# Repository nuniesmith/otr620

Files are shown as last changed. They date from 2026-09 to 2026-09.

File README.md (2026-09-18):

# Truck GPS Mount & Telemetry System (`truck-gps`)

A modular, parametric mount for the upper dash cubby in a **2022 Volvo VNL 860**, designed for a **Garmin OTR620** GPS, with integrated accessory shelves, real-time telemetry, and smart controller-based cooling/lighting.

This repository, formerly specific to the OTR620, has been restructured into a generic **`truck-gps`** project to host both mechanical (STL/CAD) files and software (Raspberry Pi/telemetry) code.

**Current status:** the repository contains the V3.1 mechanical fit prototype and earlier CAD sessions. The four v0.2 test pieces are currently being printed; physical fit results remain pending. A runnable simulation-first controller now lives in `src/pi/`: fan hysteresis, full-speed override, LED commands, sensor-fault handling and text/JSON status. Physical GPIO/PWM, live sensors, OLED, telemetry and revised cooling/power hardware remain unimplemented and untested.

Repository: [nuniesmith/truck-gps](https://github.com/nuniesmith/truck-gps).

---

## Documentation Index

- [README.md](README.md): Project overview, directory structure, system architecture, and electrical planning.
- [src/pi/README.md](src/pi/README.md): Run the controller simulation, tests, configuration and example service.
- [docs/pi-setup.md](docs/pi-setup.md): Selected fan, Pi review findings, software implementation and bench setup plan.
- [docs/todo.md](docs/todo.md): Master planning, task tracking, measurements, and physical test records.
- [docs/chats.md](docs/chats.md): Historical session logs (v0.1, v0.2, and v0.3) preserving earlier design rationale and prompts.
- [src/stl/v0.3/README.md](src/stl/v0.3/README.md): Current V3.1 print sequence, hardware, assembly and OpenSCAD export instructions.
- [docs/notes.md](docs/notes.md): Raw project ideas and planning notes.
- [docs/tomtom-api.md](docs/tomtom-api.md): TomTom Orbis Map, Routing, and Traffic API free tier and integration details.
- [docs/google-maps-api.md](docs/google-maps-api.md): Google Maps Platform free tier, Essentials, and Pro API configurations.

---

## Repository Structure

```
truck-gps/
├── README.md               # Main project file
├── docs/                   # Documentation, specifications, and notes
│   ├── todo.md             # Master task list and physical checklists
│   ├── chats.md            # Conversation archive from design sessions
│   ├── tomtom-api.md       # TomTom Orbis & legacy Maps pricing/specs
│   └── google-maps-api.md  # Google Maps pricing and capability reference
└── src/                    # Source code and physical designs
    ├── pi/                 # Runnable controller simulation; hardware and telemetry pending
    └── stl/                # 3D printer files (OpenSCAD & STLs grouped by design versions)
        ├── v0.1/           # First-generation design files
        ├── v0.2/           # Second-generation design files
        └── v0.3/           # V3.1 parametric mount & coupon test models
```

### Design sessions

| Directory | Origin | Role |
|---|---|---|
| [src/stl/v0.1](src/stl/v0.1) | First Claude session | Original insert and fit tests |
| [src/stl/v0.2](src/stl/v0.2) | Second Claude session | Rubber pads and accessory shelf |
| [src/stl/v0.3](src/stl/v0.3) | This ChatGPT session | V3.1 faceplate hardware, revised shelf and 12 STL files |

The session directory `v0.3` contains the CAD revision named **V3.1**; these are different naming schemes. Earlier `src/v0.x` paths and repository names in [the chat archive](docs/chats.md) are historical. Use the current paths above when locating files.

### First print checks

Start with [the V3.1 printing instructions](src/stl/v0.3/README.md#print-now-without-the-gps) and record results in [the task checklist](docs/todo.md#1-truck-and-accessory-tests--next-work). Print the truck frame, depth gauges, M2 hardware coupons and accessory outlines before the full assembly. The GPS housing, rear ports, gasket overlap and power requirements remain provisional until verified on the actual unit.

---

## System Architecture: Telemetry & Home Map

The truck has a stable **Starlink Wi-Fi** network, allowing the in-cab system to connect to the internet in real time.

```mermaid
flowchart TD
    subgraph Truck [Truck System]
        GPS_HW[Garmin OTR620]
        Pi_Cab[Raspberry Pi / Controller] -- Reads GPS Data --> Telemetry_Svc[Telemetry Service]
        Power_Supply[Power Delivery Module] --> Pi_Cab
        Power_Supply --> GPS_HW
    end

    subgraph Cloud [Secure Overlay Network]
        Tailscale[Tailscale VPN Overlay]
    end

    subgraph Home [Home Display System]
        Pi_Home[Raspberry Pi HDMI Receiver] -- Requests Webpage --> Pi_Cab
        TV[Home TV/Monitor] -- Renders Live Map --> Pi_Home
    end

    Pi_Cab <--> Tailscale
    Pi_Home <--> Tailscale
    Telemetry_Svc -- Serves Map & Live Position --> Pi_Home
```

### Tracking Workflow:
1. **Telemetry & GPS Capture (planned):** Select a supported GNSS input. A live position interface from the OTR620 has not been verified; an external receiver may be needed.
2. **Tailscale Private Network:** Both the truck Raspberry Pi and the home Raspberry Pi are enrolled in a private **Tailscale** network. This eliminates public IP exposure and port-forwarding issues.
3. **Home Display:** A Raspberry Pi connected to a TV/monitor at home loads a local webpage hosted by the truck Raspberry Pi via its Tailscale IP address.
4. **Real-time Map:** The page displays a high-resolution map of Canada and the United States with a custom truck icon representing your live location.
5. **Historical Logs:** The system logs traveled distance (km/miles) and states/provinces/countries visited per calendar year.
6. **Live Traffic:** The map consumes real-time traffic alerts using **TomTom Orbis Traffic** or **Google Maps** APIs on their generous free tiers.

---

## Power Strategy: Single vs. Dual USB-C Input

The front of the mounting bracket will feature physical toggle switches/buttons allowing manual control over individual power lines:
- **Main Power** (Master cut-off)
- **GPS Power**
- **Blue LEDs Power**
- **Cooling Fan Power**

We have evaluated two power routing topologies for the back of the bracket:

### Option A: Single USB-C Cable (Future candidate)
* **Description:** A single USB-C PD (Power Delivery) source powers the entire bracket. An internal buck converter regulates the input down to stable 5V lines.
* **Pros:**
  * Clean single-cable aesthetic behind the bracket.
  * Easy routing down the Volvo VNL dash.
  * Simplified physical plug-in sequence.
* **Cons:**
  * Requires robust internal step-down circuitry (e.g., converting 9V/12V PD to 5V @ 4A).
  * High-power charging (AirPods + GPS + Fan + Pi) could introduce electrical noise or heat.
  * Single point of failure for the entire system.

### Option B: Separate GPS and auxiliary supplies (Initial bring-up)
* **Description:** One USB-C cable runs directly to the Garmin GPS, while a second USB-C cable powers the Raspberry Pi and auxiliary components separately.
* **Pros:**
  * Separate supply paths for the Garmin and experimental accessories; a shared upstream source or ground can still couple faults.
  * Avoids a combined converter during initial tests; each output still needs appropriate regulation, protection and cabling.
  * If the Pi hangs or crashes, the GPS remains fully powered and functional.
* **Cons:**
  * Looks cluttered with two separate cables exiting the back of the bracket.
  * Uses up two USB power outlets in the truck's dashboard area.

---

## Selected controller: Raspberry Pi Zero 2 W

Use **Raspberry Pi Zero 2 W with Raspberry Pi OS Lite** as the host. The user selected a full Linux OS for SSH, Tailscale, telemetry and the home-map service while retaining low-level accessory control. A Pico is no longer the primary-controller plan.

I²C supports the selected OLED, 1-Wire supports the temperature sensors, and GPIO supports buttons and accessory control interfaces. Select a verified hardware PWM backend for fan speed; the old `RPi.GPIO.PWM()` example does not provide it. Keep fan control independent of network and display availability.

Allow for the board's micro-USB connectors, GPIO header, microSD access and 2.4 GHz Wi-Fi when designing the mount. [Raspberry Pi Zero 2 W specifications](https://www.raspberrypi.com/products/raspberry-pi-zero-2-w/)

Run [the controller simulation](src/pi/README.md) now, then follow [the implementation and first-boot plan](docs/pi-setup.md). The board/OS choice is settled; the exact GPIO backend, OLED, power hardware, GNSS input and mechanical layout still require selection and bench testing.

---

## Technical Specifications

### Garmin OTR620 Physical Baseline
* **Nominal Size:** 152.4 × 86.4 × 18.0 mm
* **Pocket Dimensions:** 153.8 × 87.8 × 19.0 mm
* **Mounting Type:** Secure gasketed front faceplate with 4x M2 × 6 mm screws and standard M2 nuts.
* **Operating Voltage:** Provisional branch allowance of 5 V up to 2 A, not a confirmed peak rating; verify device/adapter requirements.

### Accessory Mounts (V3.1 Shelf)
* **AirPods Pro 3 Mount:** Angled at 45° for visual access, designed around a Latercase cover. Can support a wired short right-angle USB-C cable or an embedded magnetic wireless charging puck.
* **PopSocket Mount:** Custom oval pocket designed around a MagSafe PopSocket base. Includes a recess for a 55mm OD / 43mm ID steel target ring for magnetic retention.

---

## Selected fan and thermal control

The selected fan is the **Noctua NF-A4x20 5V PWM**, four-pin. Its nominal body is 40 × 40 × 20 mm and the manufacturer lists 22 mm thickness with pads. That is a component envelope, not a finished pocket dimension. See the [verified specifications and connection table](docs/pi-setup.md#selected-fan-and-proposed-interface).

For v0.4, provide a removable mount with adjustable fit tolerance, cable access and airflow clearance. Keep ventilation separate from the speaker return duct. The existing approximately 29.8 mm rear cavity and 39.4 mm sound opening do not establish that the complete fan installation fits. Check actual hardware and the truck test results before fixing the mount dimensions.

Control goals are temperature-based speed, hysteresis, a manual override and explicit fault behavior. A 25 kHz hardware PWM implementation must be selected for the actual Pi and OS. The previous `RPi.GPIO.PWM()` example was software PWM and has been removed from active setup instructions. The old ambiguous fan wiring drawing is replaced by the [connection plan](docs/pi-setup.md#selected-fan-and-proposed-interface).

The 35–45°C ramp discussed earlier is only a bench starting proposal. Sensor faults must not be treated as 0°C. The simulation requests full cooling and reports a fault. The fan's physical boot/crash behavior still needs electrical verification. See [the complete review findings](docs/pi-setup.md#review-findings-to-resolve-in-implementation).

## Pi controller and status display

The selected host is a Pi Zero 2 W with Raspberry Pi OS Lite. The first software milestone implements simulated fan/LED control, sample parsing, fault policy, configuration and console status. Run `python3 -m truck_gps --format json` from `src/pi/` with Python 3.11+. Live sensor acquisition, GPIO/PWM adapters, buttons and OLED remain next steps; see [software instructions and tests](src/pi/README.md). The Pi controls accessories; the power-distribution hardware supplies them. Define a Linux shutdown and power-hold strategy before adding ignition or master-cutoff control.

An SSD1306 or SH1106 OLED remains planned. Select the exact module and verify its dimensions, driver, I²C address, supply/pull-ups, viewing angle and day/night readability. Its screen should show:

- Wi-Fi and Tailscale connection state with timeouts and an offline indication.
- GPS-compartment temperature, explicitly separate from Pi CPU temperature.
- Requested fan duty and measured RPM if tach feedback is installed.
- Actual controller/switch state, with unavailable power feedback labeled as unknown.

The former OLED snippet used fixed fan and switch values and CPU temperature, so it has been replaced by [implementation requirements](docs/pi-setup.md#software-status-under-srcpi). OLED or network failure must not block local cooling. Install Python dependencies in the application's virtual environment once the exact board/module stack is selected.

## v0.4 inputs

Finish and record the v0.2 fit tests, then check the v0.3 mounting tabs and M2 hardware separately. The v0.2 round PopGrip pocket does not validate the oval PopSocket. Freeze the Pi, fan, OLED, switches and cable envelopes before designing permanent openings. The next mechanical revision is planned under `src/stl/v0.4/`; no v0.4 files have been generated yet. [Detailed checklist](docs/pi-setup.md#v04-preparation-after-fit-tests)

---

## Next Planning Phases
1. **Mechanical Prototyping:** 3D print the V3.1 coupon tests and verify Volvo VNL cubby fit, M2 nut recesses, and Garmin housing dimensions.
2. **Bench Bring-up:** Follow [the Pi setup plan](docs/pi-setup.md); initially power the GPS and accessory electronics separately. Recalculate the future combined supply budget using the selected Pi and peripherals.
3. **Telemetry & Software PoC:**
   * Configure a Raspberry Pi Zero 2W with Tailscale and connect it to truck Starlink Wi-Fi.
   * Write a lightweight service in Python to process GPS NMEA data sentences.
   * Design a simple dashboard map using TomTom Orbis Web SDK / API.

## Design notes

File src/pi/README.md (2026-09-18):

# Truck GPS controller: simulation milestone

Runnable control logic for the planned **Raspberry Pi Zero 2 W / Raspberry Pi OS Lite** installation. Requires Python **3.11 or newer** and has no runtime dependencies outside the standard library. GPIO, physical sensors, fan PWM, buttons, OLED, GPS power switching and telemetry are **not implemented**. The only supported mode is `simulate`.

## Run now, without Pi hardware

From the repository root:

```sh
cd src/pi
python3 -m truck_gps --config config.example.toml
python3 -m truck_gps --config config.example.toml --format json
python3 -m unittest discover -s tests -v
```

The built-in 12-sample demo completes immediately. Each sample advances a virtual clock by five seconds. Use `--realtime` to pace samples in wall-clock time, or `--realtime --loop` for a continuous demonstration. The timestamps still represent **scenario time**, not measured sensor acquisition time. Ctrl+C or SIGTERM interrupts the wait and exits cleanly.

For an installed command, use a virtual environment:

```sh
python3 -m venv .venv
.venv/bin/python -m pip install .
.venv/bin/truck-gps --format json
```

Building the package requires setuptools; pip may download the build tooling. No Raspberry Pi or GPIO packages are needed for simulation. Keep local settings in `config.local.toml` (ignored by git); do not put credentials in configuration files committed to the repository.

## Control behavior

These values are **bench starting settings**, not validated GPS/charger protection limits. Adjust only after choosing sensor placement and measuring the actual installation.

| Condition | Requested fan duty with the example configuration |
|---|---|
| Fresh startup, valid temperature below 35°C | 0% |
| Temperature reaches 35°C | 30% |
| Temperature rises from 35°C to 45°C | Linear increase from 30% to 100% |
| Temperature at or above 45°C | 100% |
| Active fan cools below 35°C but remains above 32°C | Hold 30% |
| Temperature reaches 32°C or lower | 0% |
| Manual `boost` | 100% |
| Missing, invalid, wrong-ID or stale sensor reading | 100% and an explicit fault |

A reading becomes stale when its age **exceeds** 15 seconds. A future or invalid timestamp is a fault. Sensor faults take priority over manual mode. There is deliberately no manual force-off mode. After a fault or boost, automatic control keeps the fan active until the stop threshold is reached. Restarting the process resets the hysteresis latch and command state; it does not preserve settings from earlier runs.

The 30% minimum is a requested value, not a verified starting or sustainable fan speed. Startup kick, calibrated minimum duty, electrical fallback and measured RPM remain hardware work. A software request for full cooling cannot guarantee cooling if the fan supply or controller fails.

LEDs default off with a stored brightness of 5%. Turning them off preserves the setting. LED commands do not affect fan decisions. `--led-on`, `--led-brightness 8` and `--fan-mode boost` set **initial** commands; later scenario events can change them. Brightness alone does not enable the LEDs. In particular, the built-in demo intentionally changes LED and fan modes.

## Custom scenarios

```sh
python3 -m truck_gps --scenario scenarios/example.json --format json
```

A scenario is a JSON array. Each row must contain exactly one sample source:

- `"temperature_c": 40` for a valid numeric reading, or `null` for a missing sensor.
- `"error": "disconnected"` for a reported sensor fault.
- `"w1_text": "aa YES\naa t=35000"` to exercise parsing of a captured Linux 1-Wire text sample.

Optional fields are `age_s` (default 0), `fan_mode` (`auto` or `boost`), `led_enabled` (boolean) and `led_brightness_pct` (0–100). Command changes persist into following rows until changed again. A repeated scenario retains command and hysteresis state across the loop boundary. Temperature/source and age apply to their own row only. Unknown keys, non-finite numbers, invalid commands and malformed configuration are rejected before the simulation starts. Out-of-range finite temperatures are accepted as scenario inputs and become controller faults.

The 1-Wire parser checks the kernel's `YES` CRC result marker and temperature format. It does not independently calculate CRC or read `/sys`. There are no device reads or retry loops yet; bounded acquisition and freshness tracking must be implemented for live sensors.

## Output and verification

Text output labels all values as requests. `--format json` emits one status object per line to stdout, with logs on stderr. `simulated` is always `true`; `fan_rpm` and `gps_power` are always `null` (unknown). No RPM, GPS state or power feedback is invented. `sensor_id` identifies the configured expected sensor, not necessarily a connected device.

All 21 tests passed on Linux with Python 3.12.14. Wheel building, installation into a clean virtual environment and the installed CLI demo also passed. Tests cover the fan curve and hysteresis, fault priority/recovery, stale boundaries, malformed readings, configuration validation, LED independence, restart state, CLI output and SIGTERM handling. They verify software decisions only. No physical fan, sensor, OLED, GPIO timing or Raspberry Pi installation has been tested.

## Optional Linux service example

[`systemd/truck-gps-sim.service`](systemd/truck-gps-sim.service) is a **simulation-only template**, not a production cooling service. It loops the demo and logs JSON to the journal. To use it later, install the package in `/opt/truck-gps/.venv`, copy settings to `/etc/truck-gps/config.toml`, create a dedicated `truck-gps` service account with read access to those paths, and install the unit in `/etc/systemd/system/`. Then reload systemd and start `truck-gps-sim.service`; enable boot startup only if wanted. Use `journalctl -u truck-gps-sim.service` to inspect output.

The template deliberately denies device access. Do not adapt it for live hardware merely by removing that restriction: implement and test the GPIO/sensor adapters and their permissions first. Neither this unit nor a restart policy provides an electrical cooling fallback or a Linux power-hold/shutdown circuit.

## Next implementation work

1. Record the installed Pi OS/Python versions and verify hardware PWM support for that board/OS.
2. Select the fan interface and validate the protected 5 V branch, PWM waveform and boot/crash state on the bench.
3. Add identified live temperature sensors with bounded acquisition and stale-data handling independent of control ticks.
4. Add fan/LED adapters, debounced buttons and optional tach feedback, then an OLED using shared state.
5. Validate systemd permissions, restart and power-hold/shutdown behavior before installation in the truck.
6. Add independent GNSS logging, Tailscale and the home map later.

See [the hardware and first-boot plan](../../docs/pi-setup.md) and [the project tasks](../../docs/todo.md). The Garmin initially stays on its supplied power arrangement. v0.4 CAD awaits fit results and actual component measurements.

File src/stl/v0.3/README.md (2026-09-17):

# Garmin OTR620 / Volvo VNL 860 — V3.1 truck-fit prototype

Designed around your stated 220 × 220 mm Ender 3 Neo bed. GPS is not yet available, so this revision prioritizes the truck opening, accessory fit and reusable faceplate hardware. All dimensions are mm. Import at 100% and center each file on the bed. The GPS opening, rear feature positions, gasket compression and cable elbow fit remain provisional.

## Faceplate hardware — changed from V3

Four M2 × 6 mm machine screws enter from the front and thread into plain M2 hex nuts held in side-loading slots in the fixed insert. There are no printed screw threads. The nut sits behind the removable faceplate in a mounting tab; it stays with the insert when you remove the faceplate.

The design assumes nuts about 4 mm across flats and 1.6 mm thick. Do not substitute thicker locking nuts without changing the pocket. Print the nut and bolt-cover coupons with your actual hardware first. The main slot is 4.3 mm across flats and 1.8 mm thick. The three coupon slots are 4.1 / 4.3 / 4.5 mm from left to right, viewed with their entries at the top. Cover the open entry with removable tape after inserting the nut so it cannot slide out while the screw is absent. The slot walls prevent spinning; front and back walls retain the nut axially.

Start with pan-head or button-head screws with heads no larger than about 4 mm. Length is measured beneath the head. A nominal 6 mm screw passes through the 2.4 mm faceplate and 2 mm front bearing wall, leaving about 1.6 mm for nut engagement. Check the actual screw tip and nut using the coupons. Do not add washers or change screw length without rechecking engagement and rear clearance. Tighten gently; metal threads improve serviceability but do not make the surrounding print immune to crushing or creep.

The old side rails were too narrow for reliable nut pockets. Four small front tabs now project 6 mm beyond each side of the cubby opening. The inserted body stays 164.5 mm wide; tab/faceplate width is 176.5 mm. The tabs remain in front of the opening, but need clear, reasonably flat trim behind them. The faceplate front is 6.6 mm ahead of the nominal GPS face, plus screw heads. A rear return brings the gasket back to within 0.3 mm of the original GPS plane. This is a raised retainer, not a flush faceplate.

## Print now, without the GPS

1. **truck_fit_frame.stl** — 4 mm-deep front slice plus the new tabs. Check opening width/height, corners, floor ridges and clearance over the surrounding trim. This cannot validate the whole 50.8 mm depth.
2. **fit_gauge.stl** — two thin gauges for depth/taper and the 25.4 mm top-bar step. Check the actual floor ridges and corner fillets too. Remove the pictured existing ball mount before testing.
3. **nut_fit_test.stl** plus **bolt_cover_test.stl** — choose nut-pocket allowance, check M2 × 6 screw reach and repeated removal. These are small handling prototypes, not load tests.
4. **accessory_test.stl** — two outlines: oval PopSocket and the broad front/back outline of the AirPods Pro 3 with Latercase still installed. The AirPods opening is 64.2 × 49.2 mm with 7 mm corner radii; this is an assumption, not a measured Latercase specification. Do not force the case into the print.
5. **dash_bolt_test.stl** — check your existing nominal 1/4-inch shank / 3/8-inch hex-head dash bolts. This hardware is separate from the M2 faceplate screws. The head pocket is 9.9 mm across flats and through-hole 7 mm.
6. **pad_test.stl** — optional rubber test. Openings are 21.0 / 21.4 / 21.8 mm left-to-right. Test with a measured 20 mm-wide block plus your two pad strips, corresponding to compressed pad thicknesses of 0.5 / 0.7 / 0.9 mm per side.

After the truck gauges and accessory outline fit, **shelf.stl** can check the actual shelf position, AirPods angle and interference below the cubby. A cardboard profile first is cheaper: the shelf extends about 80.1 mm forward of the cubby face and 73.9 mm below its floor. The 45-degree tray presents the AirPods broad front face upward toward you. Its lip is 8 mm high with a lower charging/finger notch. Check lid opening, removal and retention with the real case.

**insert.stl** and **faceplate.stl** are included as provisional full parts. Defer the full insert until the truck gauges pass; defer final GPS retention decisions until the unit arrives. **usb_test.stl** and **led_carrier.stl** remain optional provisional samples.

## Ender 3 Neo starting setup

Use your installed nozzle and filament profile. If using a 0.4 mm nozzle, a practical starting point for the dimension coupons is 0.20 mm layers and 3 walls, with 4 top/bottom layers. Inspect actual small-hole toolpaths. Nut coupons are intended to bridge their short slots without internal supports; supports inside the nut pockets would be difficult to remove.

Center and print the large parts individually. All supplied STL XY bounding boxes, including 10 mm brim allowance on every side, fit inside the stated 220 × 220 mm bed. Keep brims/supports clear of bed clips, purge lines and slicer exclusion zones. No machine-specific G-code is supplied. No nozzle or filament type has been assumed as confirmed.

For the main insert, use its exported back-down orientation and review support for the upper step and external tabs. For the shelf, review support for the tongues and overhangs; a brim may help its narrow initial contact. The faceplate exports with its front on the bed and gasket return upward. The truck-fit frame may need support below projecting tabs. Verify those regions in the slicer before printing.

PLA can be used for a dimensional trial, but passing a cool-room fit does not validate a dashboard material. The filament for the installed part remains undecided. Recheck nut fit with the final material.

## Existing design retained

- Cubby envelope 164.5 × 98 × 50.8 mm, with stepped top and tapered sides, derived from your earlier measurements.
- Front sound grille and rear-to-front speaker duct.
- 1 mm uncompressed pad assumption and 0.3 mm side compression. Use small separated pads, clear of speaker, microphone, controls and ports. Adhesive must suit both rubber and print; do not assume super glue works on the flexible grip tape. Never glue the GPS in for these tests.
- Gasket channel 1.2 mm wide × 0.6 mm deep. Housing overlap 1.2 mm remains unverified. Use a separate strip or fully cure any compatible gasket compound in the removed faceplate before assembly; never clamp onto display glass.
- Rear USB opening combines a 30 × 16 mm rounded cutout and the original 20 mm circular hole. Cable-tie slots provide a starting point for jacket strain relief. Leave slack at the connector. No fitted elbow clamp yet.
- Oval PopSocket pocket assumes a 56.9 × 90 mm base with 1.2 mm total clearance. A steel target-ring recess assumes OD 55 / ID 43 / depth 1 mm; measure an actual suitable ring before finalizing it. This area does not charge anything.
- Shelf tongues and rear L-tabs are clamped by the two lower dash bolts. Full assembly is required to test that connection; the shallow truck frame does not reproduce it.
- LED carrier holes are 3.3 mm for nominal 3 mm LEDs. No installed LED location, switch opening, USB-C distribution board or wireless charger is finalized. Two 3.2 mm holes 20 mm apart remain at the shelf bottom for a future bracket.

## Assembly after measurements are confirmed

Fit the nuts from the top of each tab before installing the bracket; temporarily cover their entries. Fit shelf tongues, route the cable, and bolt the insert to the dash with appropriate backing washers/plate and locking hardware. Check what is behind drill locations and avoid crushing dash plastic. The model consumes the nominal cubby depth, so rear cable access is still needed through/around the cubby.

Place tested rubber pads, then the GPS. Fit the faceplate and its gasket and tighten the four small machine screws gently. The tabs serve as closure stops, but they cannot compensate for excessive gasket thickness or wrong GPS thickness. Confirm no pressure on glass, no obstructed microphone/speaker, charging, reception and access for removal. The accessory trays do not have positive latches; add a latch/strap if fit and magnetic hold are insufficient.

## Editable source and export

Open **otr620_vnl_v3_1.scad**. It defaults to an assembly preview with approximate devices. Legacy v2/v3 helpers remain at the beginning for traceability; the active V3.1 section is near the end. Use the commands below instead of older export comments. The legacy shelf flag and items_swap do not control the revised shelf. Nut dimensions are nut_af / nut_slot_t; case dimensions ap_w / ap_h / ap_d include the assumed Latercase.

```sh
openscad -D 'part="insert_v3"' -o insert.stl otr620_vnl_v3_1.scad
openscad -D 'part="bezel_v3"' -o faceplate.stl otr620_vnl_v3_1.scad
openscad -D 'part="shelf_v3"' -o shelf.stl otr620_vnl_v3_1.scad
openscad -D 'part="fit_frame"' -o truck_fit_frame.stl otr620_vnl_v3_1.scad
openscad -D 'part="nut_test"' -o nut_fit_test.stl otr620_vnl_v3_1.scad
openscad -D 'part="bolt_cover_test"' -o bolt_cover_test.stl otr620_vnl_v3_1.scad
```

Other part names: fit_gauge, bolt_test (dash bolts), accessory_test, usb_test, pad_test, led_carrier. Re-export all affected STLs after parameter changes. The full assembly preview is not a printable part.

## Send back after testing

Photos of the frame and gauges in the cubby; tight/loose locations and measured gaps; AirPods-with-Latercase fit; exact PopSocket base dimensions; preferred nut coupon; actual nut/screw dimensions; and filament/nozzle used. GPS-dependent changes can wait until it arrives.

Mesh and bed-size checks are recorded separately in mesh_checks.json. These establish basic geometry and nominal bed fit, not slicer compatibility, physical fit or road durability.

## Nominal print sizes (X × Y × Z)

| Part | Size, mm |
|---|---|
| truck_fit_frame.stl | 176.5 × 98.0 × 8.2 |
| insert.stl | 176.5 × 98.0 × 55.0 |
| faceplate.stl | 176.5 × 92.0 × 6.3 |
| shelf.stl | 164.5 × 131.0 × 97.9 |

## Next revision planning

This directory remains the unchanged V3.1 mechanical baseline. The user is currently printing the four v0.2 fit tests; the v0.3 tabs, M2 hardware and oval accessory fit still need their own checks.

The selected future fan is **Noctua NF-A4x20 5V PWM**, four-pin. The selected host is **Raspberry Pi Zero 2 W with Raspberry Pi OS Lite**. Neither component is fitted or modeled by this revision. Use the [Pi setup and v0.4 plan](../../../docs/pi-setup.md) for its envelope, interface, component measurements and ventilation requirements. Do not interpret the earlier 22 mm pocket proposal as verified installation clearance. Create v0.4 after the fit results and actual component dimensions are available.

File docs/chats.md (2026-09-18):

# OTR620 chats and prompts

[Current design](../README.md) · [Tasks](todo.md)

## Archive scope and completeness

This file preserves the available user messages, substantive ChatGPT responses and user-facing progress updates recorded in `Garmin_OTR620_Project_Record.docx`, followed by the documentation exchanges. The user-supplied Claude response text for v0.1 and v0.2 is placed before the ChatGPT archive so the design history can be read in session order. Historical wording and proposals are retained; use [the project README](../README.md) for current plans and [the V3.1 print instructions](../src/stl/v0.3/README.md) for the mechanical baseline.

**Claude coverage now includes all response text pasted by the user for v0.1 and v0.2.** The [Claude share](https://claude.ai/share/05fdda11-3323-4d7f-8862-223c79cbf0eb) could not be retrieved directly. The earlier user-pasted prompts remain in the “Starting the design and supplying the Claude prompts” section. The newly supplied passages include Claude progress text and final replies, but no complete raw export or exact turn-by-turn prompt pairing was supplied. Nothing missing has been reconstructed. Earlier statements that Claude replies were unavailable are preserved as historical messages.

Speaker labels and headings were added for navigation. Formatting was adapted to Markdown. Images and generated design downloads are identified by filename; they are not embedded in this three-file documentation set. Tool calls, execution logs, attachment transport messages and system instructions are excluded. This is an archive of the available conversation, not a raw platform export.

## Contents

- [Repository session mapping](#repository-session-mapping)

- [Claude session v0.1](#claude-session-v01)
- [Claude session v0.2](#claude-session-v02)
- [ChatGPT session v0.3](#chatgpt-session-v03)
- [Initial review request](#initial-review-request)
- [Starting the design and supplying the Claude prompts](#starting-the-design-and-supplying-the-claude-prompts)
- [Printer confirmation and reusable metric fasteners](#printer-confirmation-and-reusable-metric-fasteners)
- [Power distribution lighting charging and cooling](#power-distribution-lighting-charging-and-cooling)
- [Request for this project record](#request-for-this-project-record)
- [Request for repository Markdown files](#request-for-repository-markdown-files)
- [Attachment inventory](#attachment-inventory)
- [Repository layout clarification](#repository-layout-clarification)
- [Repository URL correction and rename](#repository-url-correction-and-rename)
- [Fit-test progress and Pi planning decisions](#fit-test-progress-and-pi-planning-decisions)

## Repository session mapping

| Directory | Conversation source | Available coverage |
|---|---|---|
| [`src/stl/v0.1`](../src/stl/v0.1) | First Claude session | User-pasted response text preserved below |
| [`src/stl/v0.2`](../src/stl/v0.2) | Second Claude session | User-pasted response text preserved below |
| [`src/stl/v0.3`](../src/stl/v0.3) | This ChatGPT session | Available discussion preserved below |

The user confirmed this mapping after the initial Markdown split, then supplied two blocks of Claude text. The first block is recorded as v0.1 because the second is explicitly introduced as “now for v0.2”. The older prompts and shared URL have not been assigned to a specific Claude session. A renewed attempt to open the public share returned a web-reader error without page content; this does not establish that the page requires login.

Current repository: [nuniesmith/truck-gps](https://github.com/nuniesmith/truck-gps). Access and the `src/stl/v0.1`, `src/stl/v0.2` and `src/stl/v0.3` directories were verified after the rename. Earlier paths, failed-access reports and repository URLs in the messages below are historical. The CAD revision names remain unchanged: the V3.1 prototype belongs to the `src/stl/v0.3` session.

## Claude session v0.1

Current repository directory: `src/stl/v0.1` (originally described as `src/v0.1`). Source: text pasted by the user after providing the repository URL. The concatenated progress text, wording, dimensions and historical claims are preserved as supplied. No exact message boundaries have been invented.

### Claude response text supplied by the user

Device corner radius is about 2.3 mm, so I'll use 2.0 mm pocket corners. Now writing the parametric model.All four parts exported cleanly. Now let me verify the geometry independently rather than trust the CAD.The depth gauge is too heavy for a quick test (97 cm³, hours of printing). I'll redesign it as two thin flat outline gauges that print in minutes. Checking fonts for labels first.Parts are valid and the gauges are now \~12 cm³ total. Let me slice the insert at several depths to confirm every internal feature landed where intended.Only the strip in front of the bar needs support (build-plate-only supports); the grille roof, hex seats, and duct are all self-supporting. Now rendering preview images.The section render has preview artifacts and the colors are too dark to read the internals. I'll lighten the renders and draw the section as a labeled 2D diagram instead.OpenSCAD's preview lighting leaves the faces toward the driver dark. I'll re-orient the model so the face points up toward the light and view it from above.Well lit now, just framed too tight. Letting OpenSCAD auto-fit the framing.Framing works. Now the annotated layout map (what sits where behind the GPS, bolt spots, tape spots) and labeled side sections.Good overall. A few fixes: grille slots are drawing as dots instead of slots, and some labels overlap. Tidying up.Two overlaps left (map title vs sheet title, and a bolt-section label). Fixing.Everything checks out. Delivering the files.It fits. The Garmin back-view drawing changed the design, though, and your cubby photo turned up one more catch.

**How it fits:** the OTR620 is 6.0" wide, 3.4" tall and 0.7" deep. At 3.4" it's taller than the 3-1/8" under the bar. But it's only 0.7" thick and the bar sits 1" back, so the whole GPS sits in the front inch, where you have the full 3-7/8". That leaves about a 5.5 mm frame on each side, 4 mm on top, and a 6.6 mm strip below the screen for the speaker grille.

**What the drawing and photo changed:**

- **The power key is on the back** (upper left, seen from your seat), so taping the unit in covers it. Connecting power turns the unit on, so feed it from an ignition-switched source. Bench-test what it does when power cuts out before you commit. A recess keeps anything from pressing the key, since holding it for 12 seconds resets the device.
- **The USB-C port is on the back**, with the plug pointing straight back. An open channel behind the GPS gives the plug room. A 20 mm hole in the insert's back wall marks where to drill the dash (3/4").
- **The speaker is on the back** (lower right). That open channel catches the sound, turns it down, and sends it out slots below the screen. That's your 180.
- **The mic is on the top edge**, so there's a small notch to keep voice commands and calls working. The microSD slot ends up covered, so put a card in first if you use one.
- **Your cubby's side walls taper** toward the back. From the photo I estimate about 6.2" wide at the back wall. A straight 6.5" block would jam, so the insert tapers 4 mm per side.

**Bolts:** four channels at the corners, all below the bar. The heads drop into hex-shaped pockets hidden behind the GPS, sized for 3/8" or 10 mm heads. They can't spin, so you only tighten the nuts from behind. Plan on 1-1/4" (or M6×30) bolts with washers and nylon lock nuts, assuming a dash wall around 3 mm thick.

**Before the long print:**

1. Print the three quick test pieces. 
   - The face frame checks the opening fit, the GPS fit, and whether the mic notch lines up with your unit.
   - The two flat gauges should slide in until the edge marked FRONT sits flush.
   - The bolt block checks the head fit and how much thread you'll have behind the dash.
2. Measure your GPS thickness with calipers, since that decides whether the screen sits flush. Listings say 1.8 or 1.9 cm. Every dimension is an editable setting at the top of the .scad file.
3. Print the insert in ASA or PETG (PLA will soften in a hot dash). Print it face up, with supports touching the build plate only.

**Tape:** go light. The pocket carries the weight, so a few small VHB pads in the green zones on the preview are plenty; covering the whole zones would make the GPS nearly permanent. If it ever has to come out for a reset, unbolt the insert and push the GPS out from behind through the open channel.

Since the truck is a lease, consider doing this on a spare cubby tray instead of drilling the original.

Tell me what the gauges show and I'll adjust the model. Files are below; the preview sheet shows every feature, bolt, and tape spot as seen from your seat.

## Claude session v0.2

Current repository directory: `src/stl/v0.2` (originally described as `src/v0.2`). The user introduced this block with the exact text: “now for v0.2”.

### Claude response text supplied by the user

Zero interference, and both bottom bolt paths are clear through the insert and the shelf's tabs. Now overhang checks for both big parts in their print orientations.Shelf now needs support only under the two tongues. Checking that the AirPods case and PopGrip actually fit their pockets, and the GPS its pocket.Those "overlaps" total about 0.04 mm³: the AirPods case bottom sitting exactly on the socket floor, which is contact, not a collision. The items fit. Now the renders.Nearly there. Two labels collide (the bolt-section callouts and the rubber note), so fixing placement.Sheet reads cleanly. Packaging the v2 files.I went back through the whole design and rebuilt it as v2 with the shelf and rubber pads. I checked the insert and shelf against each other for collisions and confirmed the bottom bolt paths are clear. The core fit still holds; the test prints will confirm your measurements.

**Double-check one measurement:** the 3-7/8" should run from the cubby floor (the top of the black lip at the front) to the top of the opening. From your photo, that lip looks roughly 3/8" tall. If you measured from the gray trim instead, the insert will be about 8 mm too tall. Also confirm:

- the GPS thickness
- the bolt head size
- the dash wall thickness (sets bolt length)
- the clear space below the cubby for the shelf

**Rubber pads: yes, good idea.** I widened the pocket gap to 0.7 mm per side, so 1 mm pads squeeze about 0.3 mm. Pads on the floor replace the tape and set the depth. The preview sheet shows where each pad goes.

- **Material:** use EPDM or neoprene, ideally closed-cell foam. Super glue won't hold silicone without a primer. Solid rubber pushes back much harder, so use smaller pads if yours is solid.
- **Glue:** let it cure and air out before the GPS goes in, or the fumes can leave a white haze.
- **Why it's worth it:** the GPS now comes out with a suction cup, which you'll need for resets (the power key is on the back) and to reach the bolts.
- **Pad thickness:** drop the GPS into the face-frame test, measure the gap, and aim for pads about 0.3 mm thicker than that.

**The shelf** hangs below the screen with a 45° face angled toward you:

- **AirPods slot:** sized for the Pro 3 case (47.2 mm tall, 62.2 mm wide, 21.8 mm deep) plus the Latercase, which is 0.6mm thin. It holds the bottom 30 mm and leaves about 18 mm to grab.
- **PopGrip seat:** sized for the current round MagSafe PopGrip, 2.28" across. Stick a MagSafe metal ring in the seat so it snaps in; some versions include an adhesive-backed adapter. If yours is the older oval one (56.9mm wide by 90mm long), set `pop_shape` to oval.
- **Layout:** the PopGrip is on the driver's side; `items_swap` flips the two.
- **Size:** it drops about 2-1/4" below the cubby floor and sticks out about 2-1/8". With the PopGrip collapsed, nothing rises above the floor line, so the screen and speaker slots stay clear. Check that it won't cover any switches below.

**How the shelf attaches** was the tricky part. Screws into the thin strip under the screen would be weak, and a clip-on shelf would pull loose when you yank the PopGrip off its magnet. Instead, two tongues run under the insert and turn up behind it, and your two bottom bolts pass through them. No extra hardware.

**Install order:**

1. Set the shelf's tongues on the cubby floor, with the upturned ends against the back wall.
2. Slide the insert in over them.
3. Drill the four bolt holes (the bottom two go through the tongue ends) and the 3/4" cable hole.
4. Put the bolts in, with washers and lock nuts behind the dash.
5. Feed the cable through, glue the pads, plug in, and press the GPS in.

**Test prints:**

1. **Face frame** (updated for the pads): checks the opening fit, the GPS gap, and whether the mic notch lines up.
2. **Depth gauges:** check depth, the bar step, and the wall taper.
3. **Bolt block:** checks the head fit and how much thread you'll have behind the dash.
4. **Shelf pockets:** slide the ring over the cased AirPods, and set the PopGrip in the round seat.

**Printing:** print the shelf upright, flat bottom down; only the two tongues need support. The insert prints face up as before, with support only under the strip in front of the bar.

Tell me what the tests show and I'll adjust the numbers. Files are below.

## ChatGPT session v0.3

Current repository directory: `src/stl/v0.3` (originally described as `src/v0.3`). The existing ChatGPT record follows. Claude passages appear above in session order even though they were pasted later in this conversation.

## Initial review request

### User

https://claude.ai/share/05fdda11-3323-4d7f-8862-223c79cbf0eb

can you review my chat session with claude

I want to review my 3d model and my project for any issues and also make some additions. the zip has all the 3d models that i have been working on, with some test prints i will do soon to test fitment.

also some pictures of my current progress, rubber roll that i want to use to add more padding for the gps and to help with vibrations from the truck. Also want to add support for my 90 degree usb c cables to work in the back.

Would like to go over some options to add to this current design, would be nice to add a few blue leds inside the back where the sound ducts are which would glow up and shine out the sound ducts but not be too bright. Not sure how i should power this, maybe wire a small capacitor and to control the lights, just a simple switch on the front. Want to go over ideas to add better mounting for the gps itself. Maybe put the one side into the bracket and the other side would have a clip that would hold the unit in over the top. We also could build a faceplate that could snap in after the gps goes in, not sure what would be best, support road vibrations and bumps, with a faceplate, it would be good to have a small channel to use gasket maker to have a rubberish protection on the front of the gps.

Should i add a simple usb c plug in the back of the bracket that could power the gps, power the leds, maybe also add usb plug to charge the airpods or if i can add a wireless charger to the back of the mount where the airpods go.

The airpods mount, i would like to still have the 45 angle but the other way, so the front of the airpods are facing up towards my sight. For the magsafe popsocket, i would just need to add a magnet into the bracket and glue it in, this is just to hold my popsocket and not to charge anything.

### Assistant progress

I’ll review the shared Claude chat, inspect the model files and photos, and work through options for retention, padding, cable support, lighting, and charging. I’ll distinguish what the files confirm from what still needs a measurement or fit test.

The photos show one clear mismatch: your PopSocket has an oval base, but the supplied model uses a round pocket. The GPS also relies on friction from the rubber pads, with no positive latch. I couldn’t retrieve the Claude share page, but the ZIP includes the editable OpenSCAD source, so I can review the actual geometry.

The six STL files pass a basic closed-edge check, but switching the source to its built-in oval PopSocket option triggers an “AirPods socket too close to the shelf back” assertion. That means the shelf needs a layout adjustment, not just a shape setting change.

I also found that the GPS pocket assumes 1 mm rubber compressed to 0.7 mm, and the rear cable opening has no strain relief. Those are worth resolving before the full print.

### Assistant review

**I’d keep the overall insert-and-shelf concept, but revise the GPS retention, accessory layout, and cable routing before printing the complete assembly.** Your proposed additions are practical, provided we leave room for servicing and avoid loading the GPS’s USB port.

I reviewed all seven photos, the OpenSCAD source, and all six STL files. **I couldn’t access the Claude share page**, so I haven’t reviewed the conversation itself; an exported chat or pasted transcript would let me check its reasoning too.

The STL files passed a basic check for open/non-manifold edges. That doesn’t establish strength or fit, but I found no obvious broken mesh edges.

**Issues in the current design**

| Finding | Why it matters / proposed change |
|---|---|
| PopSocket pocket is the wrong shape. The model uses a 57.9 mm round base; yours is oval. | The source has an oval option, but enabling it triggers its own “AirPods socket too close to the shelf back” assertion. The shelf needs a layout revision. |
| GPS retention is friction-only. | Rubber should prevent rattling; a mechanical retainer should prevent the GPS coming out over bumps. |
| Rubber thickness is assumed. The pocket is 153.8 × 87.8 × 19 mm, assuming a 152.4 × 86.4 × 18 mm GPS and 1 mm pads. | It assumes side pads compress to 0.7 mm. Your grip tape’s thickness and compressibility aren’t established by the photo. |
| Rear feature locations are estimates. The supplied illustration explicitly says approximately ±1–3 mm. | Verify USB, microphone, speaker, power-button, and microSD locations against the actual GPS. |
| Cable routing is just a 20 mm rear hole. | There is no elbow-shaped clearance pocket, cable clamp, or protected route for your right-angle connector. |
| The insert uses the full nominal 50.8 mm cubby depth. | A rear connector still needs space behind it or an opening through the cubby. The photographed ball mount also needs removal or explicit clearance. |
| Some sections are thin. About 1.3 mm remains between the tongue-channel roof and GPS pocket; approximately 1.62 mm remains above the microphone groove at the pocket rear. | Avoid putting latch roots, switch holes, or gasket grooves in those sections without reinforcement. |

The photo also shows floor ridges and rounded cubby corners that the simplified model doesn’t fully reproduce. Your depth gauges are useful, but they won’t validate every local interference.

**For the GPS, I favour a removable faceplate**

Your “one side hooks in, the other clips over” idea would work, particularly if you remove the GPS frequently. For truck use, my preferred starting design is:

- A padded cradle that supports the GPS at selected points.
- A separate faceplate with fixed locating hooks along one edge.
- Two small captive screws securing the opposite edge.
- A shallow gasket recess contacting only the GPS’s plastic bezel.
- Hard stops limiting gasket compression.

This distributes retention around the housing and makes the faceplate replaceable. A tool-free version could use replaceable latch tabs, but I would test those separately before relying on them.

**Keep pressure off the display glass.** We need the actual bezel dimensions before defining the faceplate overlap.

Your gasket-maker channel is feasible. I’d form and fully cure the gasket with the faceplate removed from the GPS, using a product compatible with the printed plastic and electronics. A removable silicone strip is easier to replace and gives more predictable thickness.

The grip tape can help with scuffing and rattles, but its texture alone doesn’t establish useful vibration isolation. Use small pads, keep the speaker and microphone clear, and measure its compressed thickness before changing the pocket.

**For the right-angle USB-C cable**

I’d add a clearance pocket around the complete connector body, followed by a removable clamp on the cable jacket and a little slack between clamp and connector.

The clamp should take cable pulls while allowing the padded GPS a small amount of movement. A tightly captured plug could transfer that movement straight into the USB socket.

We need three measurements with the cable **plugged into the GPS**:

1. How far it projects behind the GPS.
2. Its sideways reach, including the red strain relief.
3. Which direction the cable exits in the installed orientation.

The tape-measure photo helps identify the cable, but isn’t precise enough to finalize that pocket.

**Blue lighting through the sound ducts**

Yes—this could produce a subtle glow. I’d start with two small diffused blue LEDs, recessed where they illuminate an interior surface rather than point directly through the grille.

Use a regulated supply, a front switch controlling only the lighting, and **one current-limiting resistor per LED**. A capacitor isn’t the component that sets brightness; it can provide filtering or a short fade if we later want that.

For an illustrative 5 V circuit with a blue LED dropping approximately 3 V:

| Series resistor per LED | Approximate current |
|---|---|
| 2.2 kΩ | 0.9 mA |
| 1 kΩ | 2 mA |

Those are starting calculations, subject to the selected LED’s specifications. Begin dim and test at night. Put the switch in a dedicated shelf boss because the current GPS surround is narrow. Keep wiring secured outside the main sound path.

**Power and AirPods charging**

A single rear USB-C inlet is possible, but **it needs a proper power-distribution design, not a passive split between USB-C sockets**. USB-C uses its configuration pins to establish source/sink roles and available current. [TI’s USB-C design guide](https://www.ti.com/lit/slyy109)

My preference for the first working version is:

- Keep the Garmin on its supplied vehicle power arrangement.
- Power the LEDs and AirPods from suitable additional regulated outputs.
- Make the rear electronics carrier removable so a shared inlet can be added later.

Garmin specifies its included vehicle cable and notes that third-party adapters may charge slowly, so we should test any replacement with navigation running and a partially discharged battery. [Garmin OTR620/720 manual](https://www8.garmin.com/manuals/webhelp/GUID-3A374A49-6708-477D-9095-78BB6BD9AA70/EN-US/dezl_OTR620_and_720_OM_%28NA%29_EN-US.pdf)

For the AirPods, **wired charging is the simpler first version**. Wireless charging could use a removable, complete compatible charging puck behind the case, with its cable accessible. Confirm the AirPods model and test charging through the Latercase before sizing the holder around it.

Wireless charging also adds heat. The Garmin’s specified charging range ends at 45°C, so enclosing more electronics behind it deserves a temperature check. [Garmin specifications](https://www8.garmin.com/manuals/webhelp/GUID-3A374A49-6708-477D-9095-78BB6BD9AA70/EN-US/dezl_OTR620_and_720_OM_%28NA%29_EN-US.pdf)

**AirPods angle and PopSocket retention**

I interpret your AirPods request as **the broad front face/status light tilted upward toward your eyes**, with the hinge behind. That suggests a shallow angled cradle with side guides and a retaining lip, rather than the current deep socket. We should check lid-opening clearance and leave an opening for charging.

For the PopSocket, test a **steel target ring or plate** against its existing magnets before adding another magnet. If retention is sufficient, that avoids polarity concerns. Otherwise use a matching magnet arrangement with polarity checked before gluing. Give either insert a recessed pocket and retaining edge so glue isn’t its only restraint.

**What I’d print next**

Proceed with the face-frame, depth-gauge, and bolt-trap tests. The AirPods collar can still check cross-sectional fit, but the existing round PopSocket test doesn’t match your accessory.

After measurements, the next useful small tests are a padded GPS corner with a retainer, the USB elbow pocket, and the revised oval accessory layout. For the final dashboard part, ASA is worth considering if your printer supports it; Prusa documents its UV and temperature resistance. [Prusa ASA guidance](https://help.prusa3d.com/article/asa_1809)

Before finalizing revised geometry, please send:

- GPS dimensions and a straight-on rear photo with a ruler.
- Rubber thickness, including adhesive.
- Plugged-in cable measurements above.
- Oval PopSocket base length, width, and thickness.
- AirPods model, printer/filament, and whether you prefer tool-free GPS removal or two small faceplate screws.

**My recommended direction is a padded cradle with a secured faceplate, an upward-facing AirPods cradle, an oval magnetic parking pocket, and dim switched LEDs—with charging hardware kept modular.**

## Starting the design and supplying the Claude prompts

### User

okay can we start to design this

here are the promts from my design with claude if it helps

can you review my notes and the dims of this gps, garmin otr620, i want to fit it inside this cubby in the truck, 2022 volvo vnl 860.

Look at this picture of the cubby, the depth is different in two spots, the top has a bar across, which gives it a inch depth and the rest is 2" depth. 6.5" wide by 3.7/8" high on the outside, the inside is 3.1/8" high.

I want to design a simple 3d file i can print to put the gps inside, just using good double sided tape on the back of the gps, would be nice to see if we can add a channel for the back speaker to do a 180 and throw the sound of the front so i can hear it. I will run the power behind the insert piece so need to not block the usb c spot, also provide channels for 4 bolts on the 4 corners to i can drill through the inset to bolt this to the dash. The front can fit standard hex bolts which are 3/8" wide, and the threads are about 1/4" wide. Would like the gps to look fliush with everything and fit nicely.

can you review everything again, when i get home i will print the test prints to make sure everything looks good and fits well. Its okay to drill into this insert, this is what its for so no worries there.

Also want to see if we can add a simple shelf at the bottom of the bracket, this would hang out off the bottom, i would like to have a spot for my airpods pro 3 which has a latercase thin case, having a snug place to put them, on a 45 degress angle would be nice, also beside the airpods, i need a place to put my magsafe popsocket when i put my phone on the magsafe charger while im driving.

Should we add some thin rubber pieces for mounting the gps inside? just using thin rubber 1mm or something and super glue them down to the 3d prints.

### Assistant progress

I’ll start a parametric revision with the padded GPS cradle, removable faceplate, cable support, and revised accessory shelf. I’ll keep the unmeasured dimensions adjustable and include small fit-test parts before the full print. I’m using the Library skill to save the design package.

I’m making the AirPods holder a shallow tray at 45°, with the broad front face aimed upward toward you. The oval PopSocket pocket will run front-to-back beside it to fit the shelf width.

For this prototype, the faceplate will use four small screws and a gasket channel. It will sit about 3 mm proud of the GPS face; that gives us a replaceable retainer while keeping the existing cubby fit.

The first CAD revision has exported successfully, including the main parts and fit-test pieces. The mesh checks found no open edges.

The shelf is deeper than the original to accommodate the oval PopSocket and upward-facing AirPods. I’m checking its preview and print orientation now; I’ll include the dimensions so you can check clearance below the cubby before printing it.

The design package is ready for fit testing. The shelf extends approximately **80 mm forward** of the cubby face and **74 mm below** its floor, so check that space with a cardboard mockup first.

I’ve included tests for the cubby, bolts, rubber compression, faceplate screws, cable opening, and accessory outlines. The LEDs and charging mounts remain provisional until we select the hardware.

### Assistant V3 delivery

I’ve created the **V3 fit-test design** with editable OpenSCAD source, 11 STL files, and printing/assembly notes.

OTR620_VNL_V3_Prototype.zip

[Image shown in the session: V3 CAD preview, v3_preview.png]

It includes:

- Removable screw-fastened faceplate with a gasket channel.
- Adjustable allowances for 1 mm rubber padding.
- Larger rear USB opening and cable-tie strain relief.
- Upward-facing AirPods tray at 45°.
- Oval PopSocket pocket with a provisional steel-ring recess.
- Separate LED carrier test piece.

**Print the small fit tests first.** All STL files exported successfully and passed basic mesh-edge checks; physical fit and road retention still need testing.

The larger shelf projects approximately **80 mm forward and 74 mm below the cubby**. Check that clearance before printing it. The faceplate sits **2.7 mm proud** of the nominal GPS face.

For the rubber, use adhesive compatible with both the rubber and printed material; don’t assume super glue will hold flexible tape reliably.

**What printer and filament will you use?** That will help refine the screw fit, clearances, and print orientation.

## Printer confirmation and reusable metric fasteners

### User

220mmx220mm ender 3 neo .

i dont have the gps yet but trying to make sure everything else will fit with the truck first, my airpods 3 pro have a latercase on it. We should use small metric bolts and put nuts on the backside of the faceplate to make sure it will hold and be able to undo if we need to

### Assistant progress

I’ll change the faceplate to use small metric machine screws with captive nuts in the cradle, so it can be removed repeatedly. I’ll also check the parts against your 220 × 220 mm bed and prioritize the truck-fit tests; the GPS fit will remain provisional until it arrives.

The current side rails are too narrow for reliable nut pockets. I’m adding four small tabs in front of the dash opening, with M2 nuts held in slots behind the faceplate. This keeps the hardware clear of the GPS.

The tabs add 6 mm on each side, so the faceplate will be 176.5 mm wide and fit your bed. They also move its front surface to about 6.6 mm ahead of the GPS face.

### User

Continue

### Assistant progress

I’m finishing the nut-pocket fit tests and checking that the revised faceplate clears the mounting tabs. The package will identify what you can test now in the truck and what needs to wait for the GPS.

### User

Continue

### Assistant progress

The revised parts fit within your 220 × 220 mm bed, with room for a 10 mm brim around each part when printed separately. The AirPods test uses the assumed case-on dimensions, so you can check it with the Latercase installed.

I’m completing the final clearance check, then saving the package with the truck frame, depth gauges, accessory outlines, and M2 hardware tests listed first.

The geometry checks are complete: all 12 STL files pass the mesh-edge checks, and the faceplate clearance check found no overlap when separated slightly from its intended contact surfaces. I’m saving the updated package and hardware diagram.

### Assistant V3 point 1 delivery

**V3.1 is ready**, with metric machine screws and captive nuts replacing the screws that threaded into plastic.

OTR620_VNL_V3_Prototype.zip — updated with 12 STLs, editable source, and instructions.

[Image shown in the session: Faceplate hardware arrangement, v3_1_hardware.png]

The faceplate uses **four M2 × 6 mm screws and plain M2 hex nuts**. Nuts slide into pockets in the fixed bracket, behind the faceplate, allowing removal from the front. Test your actual hardware with the included coupons first.

The mounting tabs increase overall width to **176.5 mm** and put the faceplate **6.6 mm ahead of the nominal GPS face**. All parts fit your **220 × 220 mm bed individually**, including a 10 mm brim allowance.

Print these first:

1. **truck_fit_frame.stl** — cubby opening and surrounding trim clearance.
2. **fit_gauge.stl** — depth, taper, and top-bar clearance.
3. **accessory_test.stl** — AirPods with the Latercase installed, plus the oval PopSocket.
4. **nut_fit_test.stl + bolt_cover_test.stl** — nut fit and screw length.

All STLs passed basic mesh checks. **The GPS-dependent dimensions remain provisional** until it arrives; you can work through the truck and accessory tests now.

## Power distribution lighting charging and cooling

### User

Can we go over some of the other features, building a power distribution device for leds, powering the gps which I think it's only 1A 5V and also if we should add a wireless charger for the AirPods which is outside on the external shelf so it shouldn't cause heat issues, if there are heat issues, I can add a small noctua fan 10 or 20mm behind the gps, add some small vents from the top which would act as fresh air and we could just exhaust from the bottom speaker vents.

If it's too much to add wireless charging to the shelf for the AirPods. We can at least add a usb c port so I can plug in a small 0.5 ft usbc to usbc angle cable.

We could maybe setup a raspberry pi Pico or something to manage leds lights and power distribution.

To start I can just have the single usb c go to the gps and later add on the extra power needs for the other mods

### Assistant progress

I’ll check the Garmin’s power requirements and suitable charging, fan, and controller options, then lay out a staged design that starts with one GPS cable and leaves room for the extras.

Two details affect the design: Garmin’s manual doesn’t confirm a 5 V/1 A rating, and the Noctua “10 mm” fan is 40 × 40 mm across—10 mm refers to its nominal thickness. It would need a revised duct to fit.

The external shelf is a good place for a removable wireless charger, but we should still test charging through the Latercase and check its temperature. A fan behind the GPS would mainly cool the GPS compartment.

### Assistant electronics plan

**Yes—starting with one cable directly to the GPS is the right first stage.** We can make the electronics and AirPods charging removable upgrades, so you won’t need to replace the main mount later.

**For power distribution, I’d separate power hardware from the Pico.**

The distribution board would regulate power and protect each branch. The Pico would control brightness, read temperatures, and enable accessories. The GPS should remain powered independently of the Pico’s software.

For the expanded version, these are reasonable **provisional design allowances—not confirmed device consumption**:

| Branch | Initial allowance |
|---|---|
| GPS | 5 V, up to 2 A pending verification |
| AirPods charging | 5 V, up to 1.5 A for a compatible charging module |
| Dim blue LEDs | Approximately 5–20 mA total |
| Pico and optional fan | Reserve approximately 200 mA |
| Combined supply target | Approximately 5 V, 4 A |

I couldn’t confirm **5 V/1 A** in Garmin’s manual. It specifies the supplied vehicle power arrangement, so we should check the GPS/adapter labels and test operation while charging before choosing its final branch rating. [Garmin manual](https://www8.garmin.com/manuals/webhelp/GUID-3A374A49-6708-477D-9095-78BB6BD9AA70/EN-US/dezl_OTR620_and_720_OM_%28NA%29_EN-US.pdf)

For a future single-cable inlet, one candidate architecture is:

- Automotive USB-C PD adapter outside the printed enclosure.
- Rear USB-C input with a PD controller requesting a supported **9 V/3 A** supply.
- A suitably rated converter providing regulated **5 V**, with separate protected outputs.
- GPS branch independent of accessory switching.
- Switchable AirPods, LED, and fan branches.

That provides more expansion room than a basic 5 V/3 A input. We must select the adapter and converter together; a charger’s “30 W” label alone doesn’t establish its output at every voltage. USB-C output ports also need proper connection detection and current advertising—not simply a socket connected to two power wires. [TI USB-C guide](https://www.ti.com/lit/slyy109)

**Wireless charging is worth allowing for on the shelf.**

Your AirPods Pro 3 support Qi-certified, MagSafe, Apple Watch, and USB-C charging. [Apple specifications](https://www.apple.com/airpods-pro/specs/)

I’d make the AirPods tray accept an interchangeable backing:

| Version | Design |
|---|---|
| Initial | Plain backing, accessible shelf USB-C port, short angled cable |
| Upgrade | Removable cradle for a complete compatible wireless charging puck |

For wireless charging, position the puck directly against the Latercase through an opening in the tray, minimizing extra plastic between the charger and case. Keep the PopSocket’s metal target and magnets outside the charging area.

The external shelf improves ventilation, but **doesn’t eliminate heat from charging, misalignment, or sunlight**. Test the chosen puck with the Latercase installed before designing its mounting recess. A complete charger is a better starting point than embedding a bare coil and designing its control electronics.

**I’d reserve fan space, then decide whether to install it after temperature testing.**

One size detail: the Noctua NF-A4x10 5V is nominally **40 × 40 × 10 mm**; its listed dimensions reach 12 mm thick with pads. It isn’t a 10 mm-wide fan. [Noctua specifications](https://www.noctua.at/en/products/nf-a4x10-5v/specifications)

In our current model:

- The lower cavity behind the GPS is approximately **29.8 mm deep**.
- The sound-window opening is only **39.4 mm high**.
- Therefore, a 40 mm fan requires a geometry change and clearance for airflow, wiring, and the USB elbow.

Your top-intake/bottom-exhaust arrangement can work with forced airflow, provided the intake actually reaches cabin air rather than a closed space behind the dash. However, sharing the speaker duct could add fan noise and restrict airflow.

My preference would be **a separate ventilation passage**, with passive lower intake and upper exhaust where practical, plus an optional fan. A fan behind the GPS won’t directly cool the AirPods charging interface, and cannot cool either device below the incoming air temperature. Garmin specifies a charging temperature range of **0–45°C**. [Garmin specifications](https://www8.garmin.com/manuals/webhelp/GUID-3A374A49-6708-477D-9095-78BB6BD9AA70/EN-US/dezl_OTR620_and_720_OM_%28NA%29_EN-US.pdf)

**A Pico would be useful once you want automatic control.**

Its PWM and analogue-input capabilities suit LED dimming and temperature sensing. [Raspberry Pi documentation](https://www.raspberrypi.com/documentation/microcontrollers/pico-series.html)

I’d give it these jobs:

- Remember a dim LED brightness setting.
- Read an external temperature sensor near the GPS and another near the charger.
- Control accessory power through suitable load switches or MOSFETs.
- Turn the fan on and off with enough temperature separation to avoid constant cycling.
- Disable wireless charging if its measured temperature becomes excessive.

The fan and charging loads would draw from the distribution board, **not from Pico GPIO pins**.

For the next mechanical revision, I’d reserve a removable electronics carrier, a blanked shelf USB-C opening, an interchangeable AirPods backing, and cable channels. **We can leave the fan and charging hardware uninstalled while you test the truck fit and run the GPS directly from its supplied adapter.**

## Request for this project record

### User

can you write a doc with all of this text from the session and a overview of what we went over and plans for the future

### Assistant progress for the document

I’ll create a Word document with the project overview, design decisions, future plans, and a chronological transcript of the discussion. I’ll clearly mark the dimensions that still need verification and note that the original Claude chat wasn’t accessible.

I’m using the Documents skill to put the current V3.1 overview and future plan first, followed by the conversation record. The transcript will preserve earlier proposals while the overview makes clear which ones were superseded—especially the faceplate fasteners and its increased projection.

The draft includes the overview, staged upgrade plan, current file inventory, and conversation record. I’m checking the Word layout now, particularly the tables, hardware diagram, and transcript page breaks.

### Assistant document delivery

Created a 17-page Word document with the conversation record, current V3.1 design overview, fit-testing steps, and future power, lighting, charging, and cooling plans.

Garmin_OTR620_Project_Record.docx

## Request for repository Markdown files

### User

can you split this into 3 files now for my otr620 repo on github, README.md, chats.md (all the full chat details from both claude and chatgpt and prompts), todo.md (tasks to work on)

### Assistant progress

I’ll split the project record into `README.md`, `chats.md`, and `todo.md` for your repo. I’ll preserve the available conversation text and clearly mark the missing portion of the original Claude chat.

I’m using the Library skill to save the three Markdown files. The README will describe the current design, `chats.md` will retain the historical discussion, and `todo.md` will separate completed work from pending tests and upgrades.

## Attachment inventory

Original supplied files:

- `2.zip`
- `att.vMFiQBYX14YBz7hegkXZV5H3_4Se0xIlSuxjnK33N3w.jpg`
- `IMG_0040.JPEG`
- `IMG_0041.JPEG`
- `IMG_0044.PNG`
- `IMG_0051.JPEG`
- `IMG_0052.JPEG`
- `IMG_0053.JPEG`

Generated artifacts referenced in the session:

- `OTR620_VNL_V3_Prototype.zip` — updated internally to V3.1; current package contains 12 STL files and editable OpenSCAD source.
- `v3_preview.png` — historical V3 preview, before V3.1 nut tabs.
- `v3_1_hardware.png` — V3.1 faceplate fastener diagram.
- `Garmin_OTR620_Project_Record.docx` — 17-page project record used for this split.

## Repository layout clarification

### Assistant final progress for the Markdown split

The three files are drafted, with the existing conversation text preserved and a prioritized task checklist added. `chats.md` includes the Claude prompts you pasted, but the full Claude replies remain unavailable; I’ve noted that gap explicitly.

Saving the three files to Library now. They’re ready to add to your repository.

### Assistant Markdown delivery

Ready to add to your repo:

- README.md — current design, dimensions and overview.
- chats.md — available conversation and prompts.
- todo.md — completed work, prioritized tasks and testing checklist.

The chat archive includes your pasted Claude prompts; Claude’s full replies remain unavailable and are marked as missing.

### User

https://claude.ai/share/05fdda11-3323-4d7f-8862-223c79cbf0eb

this link is public and you should be able to read without a login, if not then i can paste the whole chat session

also my 3 seperate sessions are under src/v0.1, v0.2, and v0.3 on my repo 0.3 is this session and 1 and 2 are with claude

### Assistant progress

I’ll retry the public Claude link. I’ll also update the documentation to identify `src/v0.1` and `src/v0.2` as the Claude sessions and `src/v0.3` as this ChatGPT session.

The retry failed in my web reader before it returned any page content, so I can’t tell whether the page would open normally in a browser. Please paste the full chat when convenient.

I’ll keep your repository session numbers separate from the earlier CAD labels: the V3.1 prototype belongs to `src/v0.3`.

## Repository URL and Claude text supplied

### User

https://github.com/nuniesmith/otr620repo

[Archive placement note: the remainder of this user message is preserved in full in the Claude v0.1 and v0.2 sections above. Its dividing text was “now for v0.2”.]

### Assistant progress

I’ll check the repository through the GitHub plugin, add the supplied Claude text under `v0.1` and `v0.2`, and update the overview and tasks to reflect any details missing from our record.

The GitHub plugin returned “Not Found” for `nuniesmith/otr620repo`, so I haven’t been able to inspect its files. I can still finish updating the three documents from the text you supplied.

The Claude notes add a key fit check: measure the cubby height from the top of the black floor lip. They also describe the older friction-fit GPS retention and round PopGrip pocket, which I’ll preserve as historical designs alongside the later changes.

Archive cutoff: the supplied Claude response blocks, repository URL and progress updates above. All supplied Claude response text is included; any additional original prompts, code blocks or omitted turns can be appended with their session labels when available.

## Repository URL correction and rename

### Assistant delivery after integrating Claude text

Updated all three files with the supplied Claude text:

- README.md — design history and recovered fit checks.
- chats.md — both Claude blocks preserved in full under `v0.1` and `v0.2`, alongside this ChatGPT session.
- todo.md — updated tasks and measurements.

GitHub returned “Not Found” for `nuniesmith/otr620repo`, so no repository changes were made. Please confirm the URL and, if it’s private, that the GitHub connection has access.

### User

https://github.com/nuniesmith/otr620.git

### Assistant progress

I’ll check `nuniesmith/otr620`, compare its documentation with our updated files, and prepare the changes on a review branch.

### User

@GitHub i changed the name to truck-gps on my nuniesmith account

https://github.com/nuniesmith/truck-gps.git

### Assistant progress

I’ll use `nuniesmith/truck-gps` and continue preparing the documentation changes there.

Access works now. The repository already contains our documents, plus newer telemetry, cooling, and OLED plans. The model folders are now under `src/stl/v0.1` through `src/stl/v0.3`.

I’ll preserve those newer plans and make a focused documentation update: fix links and session paths, distinguish the existing prototype from planned software, and add the repository rename to the chat record.

Archive update: the repository URL correction, rename and access result are included above. The older archive cutoff refers to the previous snapshot; all earlier supplied Claude response passages remain intact.

## Fit-test progress and Pi planning decisions

### User

merged

### Assistant

Great—those documentation updates are now in the main branch. We can use `truck-gps` as the working project record going forward.

### User

right now i am printing the 4 test files from v0.2

### Assistant

Good—those v0.2 tests will help establish the truck fit. Record these results:

| Test | What to check |
|---|---|
| Face frame | Opening, corners and floor ridges. Measure height from the **top of the black floor lip**, not the gray trim. |
| Depth gauges | Both seat with **FRONT flush**, without forcing; check the top bar and side-wall taper. |
| Bolt trap | Actual bolt head fits without spinning; shank passes through. |
| Shelf pockets | AirPods fit with the **Latercase installed**. The round PopGrip pocket won’t validate your oval PopSocket. |

Take photos of any tight areas and measure gaps where possible. These tests won’t check the newer v0.3 faceplate tabs or M2 nut pockets—we’ll test those separately. GPS fit can wait until it arrives.

### User

can you review my src/pi and see what code i need to setup for when i get to the pi, once finished with these test pieces, we can start to build the v0.4 files we need

### Assistant review

I reviewed the current `main` branch. **There’s no `src/pi` code committed yet**—the fan and OLED examples are still inside the [README](https://github.com/nuniesmith/truck-gps/blob/f8075d72dddf59a85583dda3cea287938e356ffc/README.md). They’re useful starting points, but need corrections before running on hardware.

**The main issues I found:**

| Issue | What needs changing |
|---|---|
| Missing temperature sensor crashes the example | `read_temp_raw()` returns an empty string, then `read_temp()` indexes it. Handle missing, disconnected and malformed sensors explicitly. |
| Sensor retries can run forever | The CRC retry loop needs a timeout. A failed reading should produce a fault state, not `0°C`, which currently turns cooling off. |
| Fan control is described as hardware PWM but uses software PWM | `RPi.GPIO.PWM()` does not enable hardware PWM simply because it uses GPIO18. Choose a hardware PWM implementation compatible with the selected Pi and OS. [RPi.GPIO documentation](https://pypi.org/project/RPi.GPIO/) |
| Wiring diagram is ambiguous | The fan PWM line appears joined to the ground line. Replace it with a clear connection table and verify the selected fan’s electrical interface. Noctua specifies a **25 kHz target**. [Noctua PWM specifications](https://noctua.at/pub/media/wysiwyg/Noctua_PWM_specifications_white_paper.pdf) |
| OLED reports invented operating states | Fan speed is fixed at `"45%"`, GPS at `"ON"`, and LEDs at `"OFF"`. Its temperature is the Pi CPU temperature, not the GPS compartment. Display actual controller state and label temperatures separately. |
| Power-off behavior isn’t implemented | A Linux Pi needs a shutdown/power-loss plan. A GPIO button alone cannot maintain power long enough to finish shutdown. |
| GPS tracking input is unresolved | The repository hasn’t established that the OTR620 provides a usable live position stream. Plan around a supported GNSS receiver unless we verify a Garmin interface. |

The README also switches between **10 mm and 20 mm fans**. We need one exact model before designing its v0.4 mount.

For your SSH, Tailscale and home-map plans, my starting choice would be a **Pi Zero 2 W running Raspberry Pi OS Lite**. A Pico could remain an optional accessory controller later. The Zero 2 W has **2.4 GHz Wi-Fi and micro-USB connectors**, which matters for both Starlink connectivity and our mounting layout. [Raspberry Pi specifications](https://www.raspberrypi.com/products/raspberry-pi-zero-2-w/)

The first software milestone should contain these pieces:

| Proposed file under `src/pi/` | Purpose |
|---|---|
| `README.md` | Installation, wiring, first boot and troubleshooting |
| `pyproject.toml` | Dependencies and application entry point |
| `config.example.toml` | Pin assignments, sensor ID, thresholds and enabled accessories |
| `truck_gps/sensors.py` | Temperature readings with timeouts and fault reporting |
| `truck_gps/controller.py` | Fan curve, hysteresis, LED brightness and button handling |
| `truck_gps/hardware.py` | Hardware adapters plus a simulated mode for laptop testing |
| `truck_gps/display.py` | OLED showing real state; display failure must not stop cooling |
| `truck_gps/main.py` | Startup, logging, shutdown and shared application state |
| `systemd/truck-gps.service` | Automatic startup and restart after failure |
| `tests/` | Sensor disconnects, invalid readings, fan thresholds and restart behavior |

**When the Pi arrives**, the setup sequence should be:

1. Install OS Lite with Wi-Fi and SSH configured through Raspberry Pi Imager. [Official setup guide](https://www.raspberrypi.com/documentation/computers/getting-started.html)
2. Configure Tailscale and verify remote access. [Linux installation guide](https://tailscale.com/docs/install/linux)
3. Enable I²C and 1-Wire, then test the temperature sensor and OLED individually.
4. Test fan control and LEDs on the bench.
5. Install the service and test sensor disconnection, reboot and network loss.
6. Add location logging and the home-map service afterward.

For **v0.4**, your current v0.2 test prints will establish the cubby, depth and accessory corrections. We’ll also need the newer faceplate/nut-pocket tests and actual dimensions of the Pi, fan, display, switches and power hardware. That gives us enough to design the electronics carrier and revised faceplate without guessing cutouts.

This was a review of the committed examples; I haven’t changed code or created v0.4 files.

### User

for the fan id rather use the 20mm one since its PWM and we can get the 4 pin and control the speed too

### Assistant

We’ll use the **Noctua NF-A4x20 5V PWM**, the **40 × 40 × 20 mm, four-pin version**, as the planned fan.

For v0.4, we’ll provide:

- Adjustable mounting clearance for its pads, connector and wiring.
- A ventilation path separate from the speaker duct.
- Temperature-based speed control and a manual override.

The previously proposed **22 mm pocket depth remains provisional** until we verify the fan’s full envelope and airflow clearance. Make sure the selected model says **5V PWM**.

### User

can you update all the docs and push to main and open a pr

### Assistant progress

I’ll update the current documentation with the selected 20 mm, four-pin 5V PWM fan and the Pi setup findings. I’ll open a PR for the changes, then merge it into `main` so the update has a review record.

Noctua lists the selected fan as 40 × 40 × 20 mm, or 22 mm thick with its pads. That means 22 mm is the fan’s physical envelope; the mount still needs additional fit and airflow clearance.

I’m correcting the fan references and wiring guidance, recording the Pi code issues, and adding a setup plan and v0.4 checklist based on the measurements we still need.

### User

update for the future to use the pi zero, so we can get a full OS with all the features and still setup the low level things we need to do

### Assistant progress

I’ll make the **Raspberry Pi Zero 2 W with Raspberry Pi OS Lite** the selected host. That gives us Linux for SSH, Tailscale and the web services, plus GPIO, I²C, 1-Wire and a verified hardware PWM setup for accessory control. I’ll include that decision in this update.

Archive note: the final host decision above supersedes the earlier Pico/Zero comparison. The hardware PWM backend is a requirement still to implement and verify, not working code. See [the current setup plan](pi-setup.md).

## Controller simulation milestone — September 18, 2026

Archive note: the following records the available continuation prompts and a labelled implementation summary. It does not reconstruct missing assistant messages verbatim.

### User

What can we work on next?

### User

Okay continue

### User

continue

### Implementation summary

Continued the Pi Zero 2 W software work while physical fit results remain pending. Created `src/pi/` with a simulation-only controller, fan curve and hysteresis, auto/full-speed boost modes, LED commands, captured sensor-text parsing, fault handling, validated configuration, scenarios, text/JSON status and an optional simulation service template. Added 21 passing software tests. The simulation does not access GPIO, measure RPM, switch GPS power or read physical sensors. Physical integration and v0.4 CAD remain future work. See [the package README](../src/pi/README.md) for the current behavior and limitations.

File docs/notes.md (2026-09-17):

# This is for raw notes, ideas to be transferred over to the repos docs

need to research how i can use a raspberry pi pico 2W to add to the project to control the blue leds, fan (if needed), power management so i can use a single usb c into the pi, the pi can power the gps, lights, charge the airpods with a usb c connector or wireless charging built into the airpods mount.
the front of the bracket we can add buttons to control the pi for main power, power for the gps, power for the lights, and power for the fan etc. 
I do have wifi in the truck with starlink so the pi can connect to the wifi for playing with it once its installed to add more features, might look into
adding gps tracking for when im driving later on, i should be able to ssh into the pi depending what OS we use, note sure if we can run a ubuntu base OS or not. In the future, would be nice to keep track of km/miles travelled, states/provinces/countries travelled to for the calandar year. Later i might use this gps into to feed into a map and traffic api to get real time traffic updates. I know tomtom has a free api to play with, more live traffic updates are a good thing. The garmin gps is pretty good at making sure i am on the right road with a big truck at 13'6" standard reefer trailers usually.

review the pdf with the tomtom free api starting points, i think for my personal use, it should be enough to play with later on with a pi into this unit.

Go over the pros and cons of having 1 or 2 usb c cables into the back of the bracket. If we have 2, we can power the pi and the gps separately, if we have 1, we can power both with the same usb c cable. The gps doesn't need much power, 5V at 1A so there should be enough power for the pi to power the gps but might add extra failure points.

Google also has a free tier with their maps api, so we could build different map apis and use them on the free tier and also get differet sources for live traffic.

Another idea, with the pi having gps data and tracking it, i would like to setup a physical map of canada and USA at home for the wife, this would have a little truck on the map of where i am in real time. At home, something like a small tv/monitor with another pi to hdmi would work fine i am sure. Since everything has tailscale on it, i am sure the pi pico will have tailscale if possible. Making it easy to using client devices to lookup a webpage over tailscale to view the map with live real-time location of my truck.

update the docs to include the new structure of dirs for this repo and changed the name to truck-gps to be more generic. We can put any pi code under src/pi and stl files for 3d printer code under src/stl.

Review the pdf's under doc and convert them into their own md file, then we can delete the pdf's.

## Current decisions following the Pi review

The raw notes above remain the original ideas. The current selected fan is the **Noctua NF-A4x20 5V PWM**, four-pin. Its mount and ventilation remain v0.4 work pending fit tests and actual hardware dimensions. See [Pi setup and implementation](pi-setup.md) for the verified fan table and review findings.

The selected Linux host is **Raspberry Pi Zero 2 W with Raspberry Pi OS Lite**, confirmed by the user for a full OS and low-level peripheral control. Accessories draw from rated power-distribution hardware, not Pi GPIO. The GPS's suggested 5 V/1 A demand and a live Garmin position interface remain unverified. Begin with direct Garmin power, then bench-test accessory control. The four v0.2 test prints are in progress; v0.4 CAD has not started.

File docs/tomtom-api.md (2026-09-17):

# TomTom API & Pricing Reference

Source: [TomTom Pricing](https://docs.tomtom.com/pricing) (Retrieved September 2026)

## Overview
TomTom offers a generous free tier for developers with no credit card required upfront. Pricing is usage-based (pay-as-you-grow) with high monthly free request quotas per API.

---

## TomTom Maps vs. TomTom Orbis Maps

### TomTom Orbis Maps (Latest Generation)
* **Description:** TomTom's latest cloud-native map platform.
* **Features:** Richer map data, higher update frequency, and improved support for advanced use cases (EV routing, real-time traffic, precise geocoding).
* **Recommendation:** Use Orbis Maps for all new integrations to benefit from the latest features, performance improvements, and long-term support.

### TomTom Maps (Legacy Platform)
* **Description:** Previous-generation map platform.
* **Status:** Supported but being deprecated as equivalent or improved functionality is added to Orbis.

---

## Free Monthly Quotas by API

TomTom provides high-volume free monthly requests. Below is a breakdown of the free limits:

### 1. Map Display APIs
* **Map Display API Vector Tiles (Orbis):** **200,000 requests / month** free.
  * *Use case:* Serve and render vector tiles in your application.
* **Map Display API Raster Tiles (Orbis & Legacy):** **200,000 requests / month** free.
  * *Use case:* Serve and render raster tiles for map displays.
* **Map Display API Raster Non-Tile (Legacy):** **20,000 requests / month** free.

### 2. Navigation & Routing APIs
* **Routing API (Orbis & Legacy):** **20,000 requests / month** free.
  * *Use case:* Calculate optimal routes with traffic, vehicle settings (such as height/weight for large trucks), and waypoints.
* **Matrix Routing API (Legacy):** **2,500 requests / month** free.
  * *Use case:* Get travel times and distances for multiple origin-destination pairs.
* **Snap to Roads API (Legacy):** **2,500 requests / month** free.
  * *Use case:* Snap raw GPS traces to the road network and retrieve speed limits, lanes, etc.
* **Long Distance EV Routing API (Legacy):** **2,500 requests / month** free.
  * *Use case:* Plan EV trips with smart charging stops along the route.
* **Reachable Range API (Legacy):** **2,500 requests / month** free.
  * *Use case:* Calculate the reachable polygon from a given location.

### 3. Places & Search APIs
* **Places Search API Suggest (Orbis):** **10,000 requests / month** free.
  * *Use case:* Return place suggestions in real-time as users type.
* **Places Search API Details (Orbis):** **5,000 requests / month** free.
  * *Use case:* Retrieve detailed attributes for a single point of interest (POI).
* **Places Search API Discover (Orbis):** **5,000 requests / month** free.
  * *Use case:* Discover POIs and locations near a point.
* **Geocoding API (Orbis & Legacy):** **20,000 requests / month** free.
  * *Use case:* Convert textual addresses into geographic coordinates.
* **Reverse Geocoding API (Orbis & Legacy):** **20,000 requests / month** free.
  * *Use case:* Convert coordinates into human-readable addresses.

### 4. Traffic APIs
* **Traffic Incidents API Details (Orbis & Legacy):** **2,500 requests / month** free.
  * *Use case:* Retrieve real-time detailed incident data.
* **Traffic Flow & Incidents Vector/Raster Tiles (Orbis & Legacy):** **200,000 requests / month** free.
  * *Use case:* Render real-time traffic flows and incidents as tiles.
* **Traffic Flow API Segment Data (Legacy):** **20,000 requests / month** free.
  * *Use case:* Access speed and flow data at the individual road-segment level.

---

## Commercial & Automotive Only APIs
* **Fuel Prices API:** Contact Sales (Automotive only) - Get real-time fuel prices near any location.
* **Parking API:** Contact Sales (Automotive only) - Find parking availability, prices, and on-street spots.
* **Connected Services API, Traffic Stats, O/D Analysis, Junction Analytics, Area Analytics, Route Monitoring:** Contact Sales.

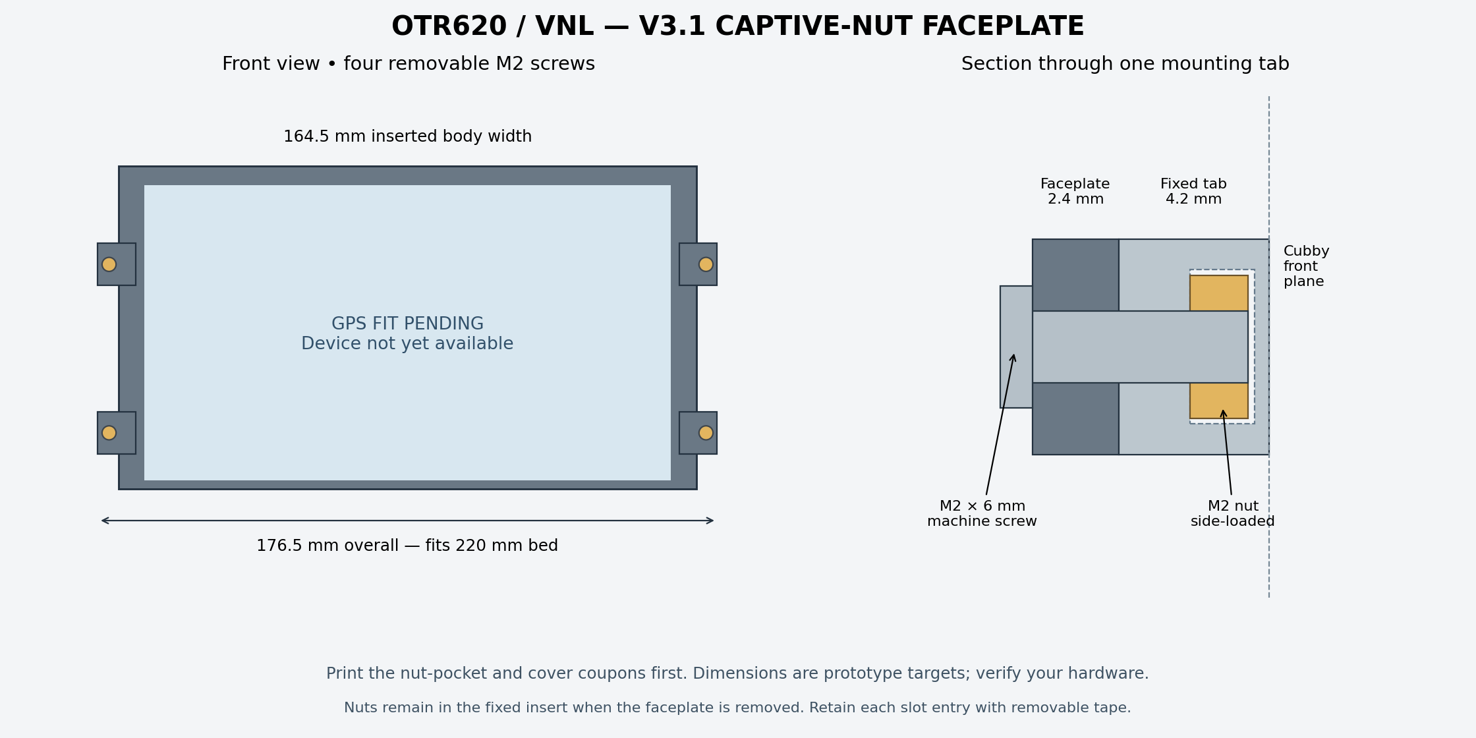
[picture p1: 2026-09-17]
src/stl/v0.3/v3_1_hardware.png

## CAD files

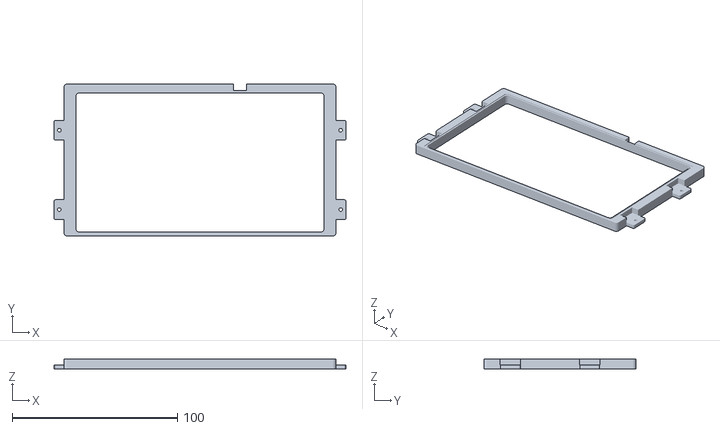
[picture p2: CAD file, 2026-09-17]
src/stl/v0.3/faceplate.stl
176.5 x 92.0 x 6.30

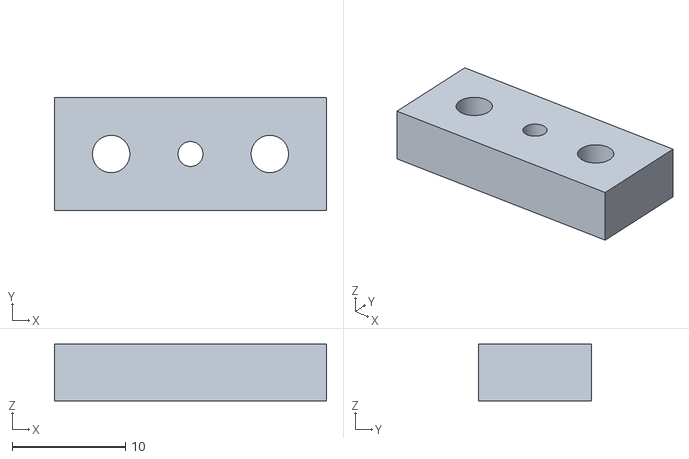
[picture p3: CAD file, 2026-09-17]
src/stl/v0.3/led_carrier.stl
24.0 x 10.0 x 5.00

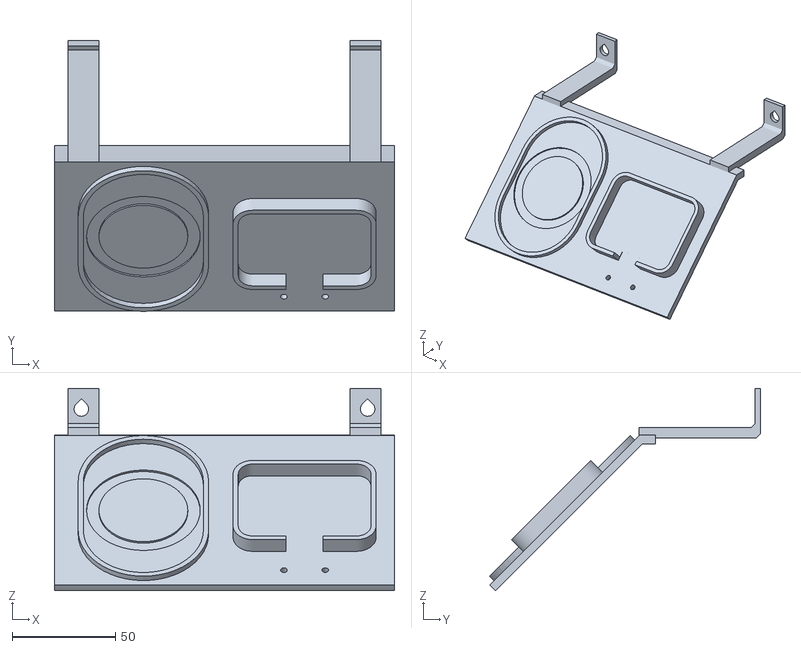
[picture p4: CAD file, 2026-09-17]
src/stl/v0.3/shelf.stl
164.5 x 131.0 x 97.9

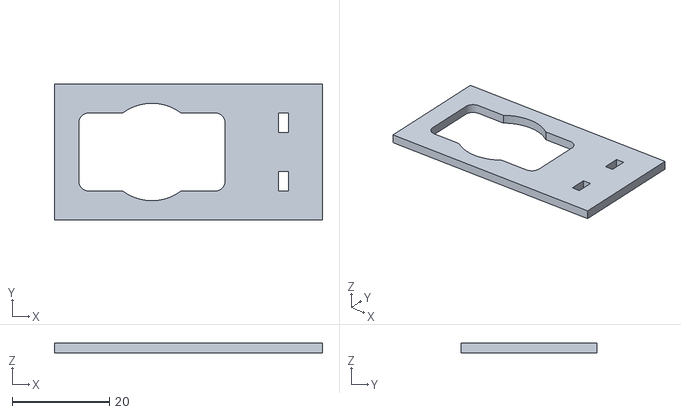
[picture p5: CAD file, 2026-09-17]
src/stl/v0.3/usb_test.stl
55.0 x 28.0 x 2.00

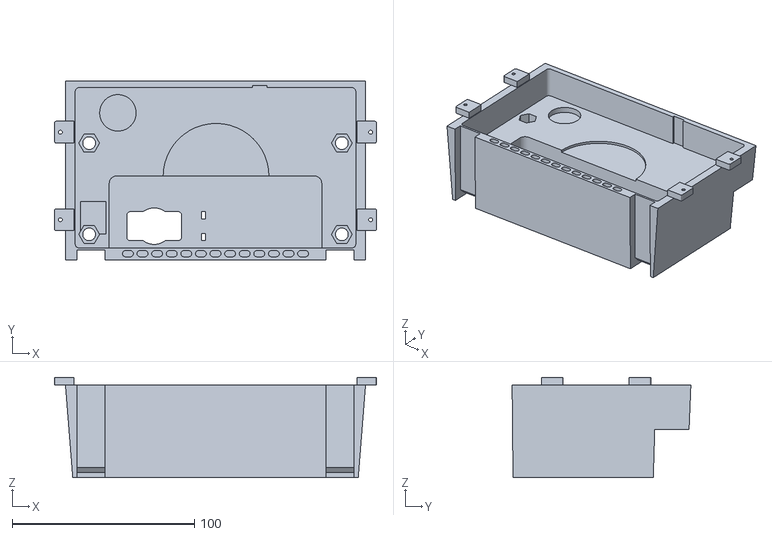
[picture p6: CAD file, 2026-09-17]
src/stl/v0.3/insert.stl
176.5 x 98.0 x 55.0

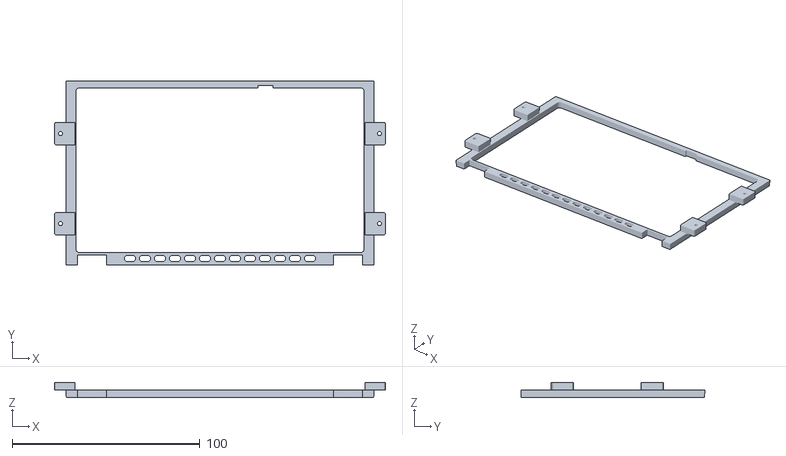
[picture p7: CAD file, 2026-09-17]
src/stl/v0.3/truck_fit_frame.stl
176.5 x 98.0 x 8.20

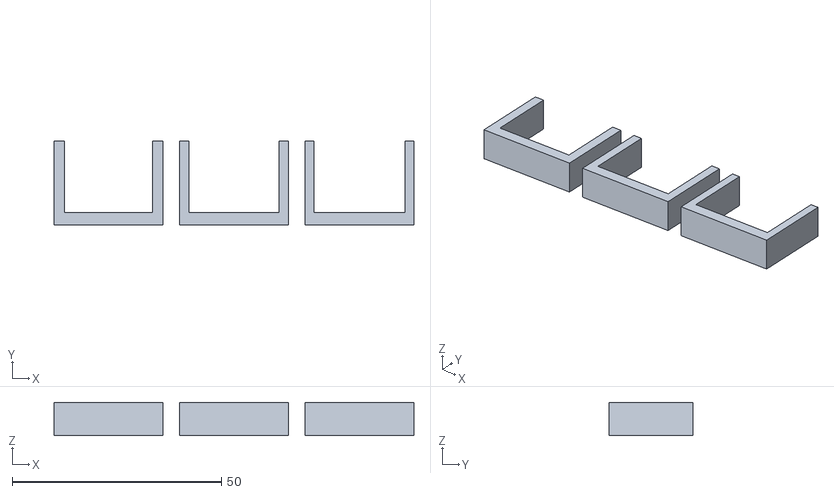
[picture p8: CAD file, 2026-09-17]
src/stl/v0.3/pad_test.stl
86.0 x 20.0 x 8.00

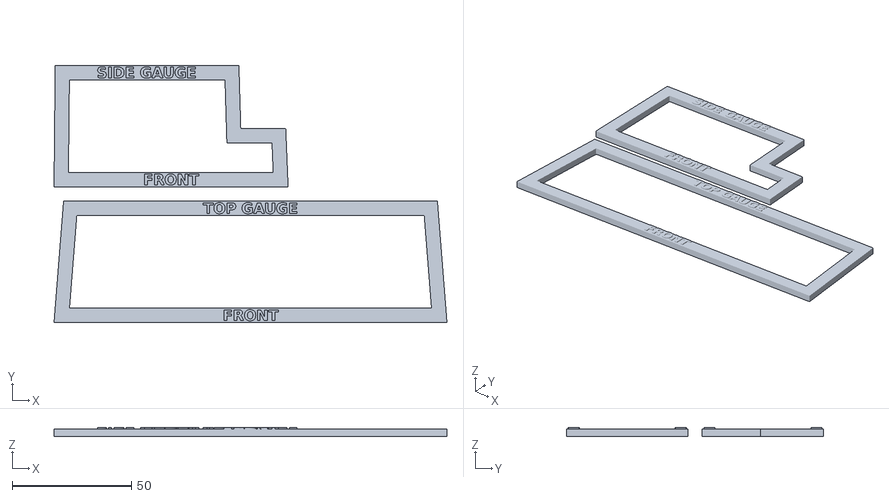
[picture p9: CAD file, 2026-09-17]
src/stl/v0.3/fit_gauge.stl
164.5 x 107.6 x 3.60

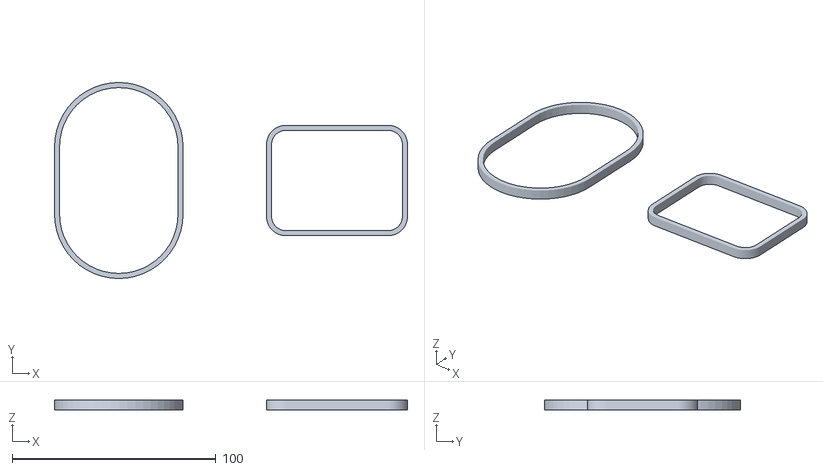
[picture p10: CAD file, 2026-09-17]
src/stl/v0.3/accessory_test.stl
173.2 x 96.2 x 5.00

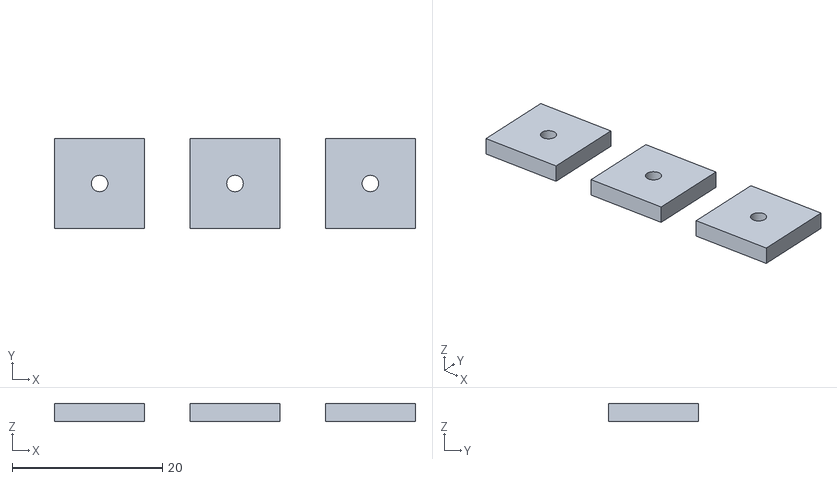
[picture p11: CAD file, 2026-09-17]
src/stl/v0.3/bolt_cover_test.stl
48.0 x 12.0 x 2.40

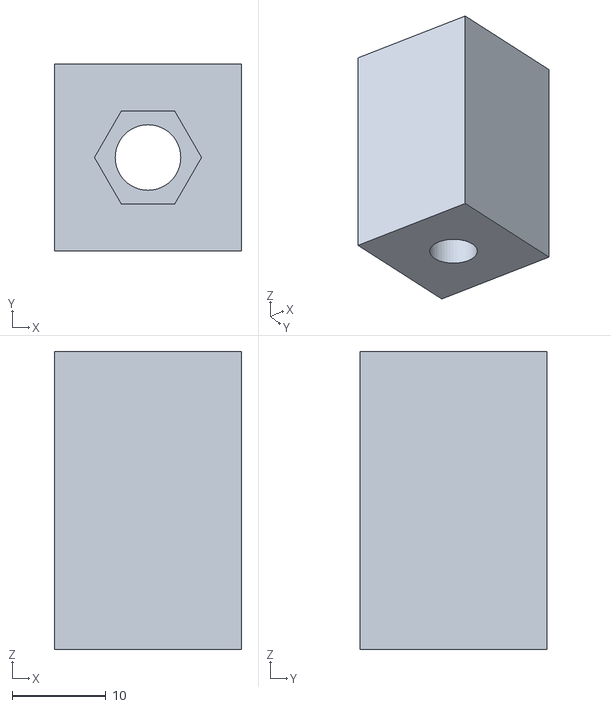
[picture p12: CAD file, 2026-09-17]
src/stl/v0.3/dash_bolt_test.stl
20.0 x 20.0 x 31.8

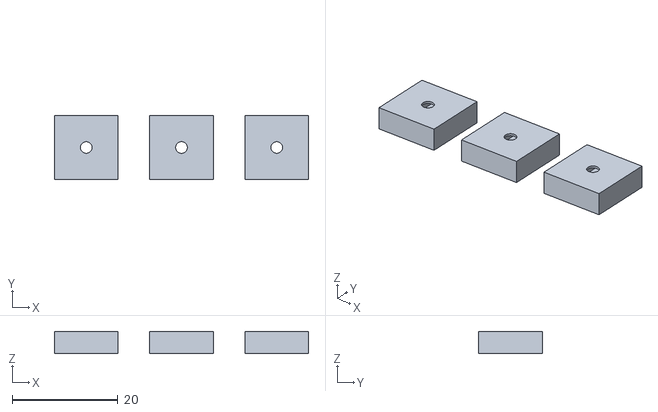
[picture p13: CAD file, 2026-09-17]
src/stl/v0.3/nut_fit_test.stl
48.0 x 12.0 x 4.20

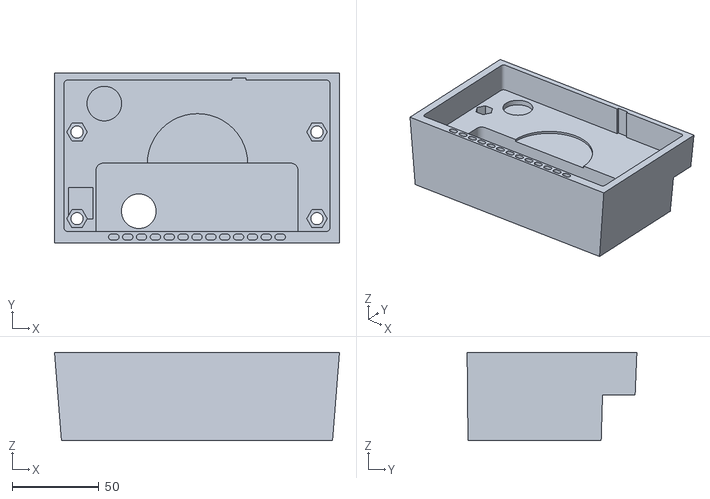
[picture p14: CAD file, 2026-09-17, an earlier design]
src/stl/v0.1/otr620_insert.stl
164.5 x 98.0 x 50.8

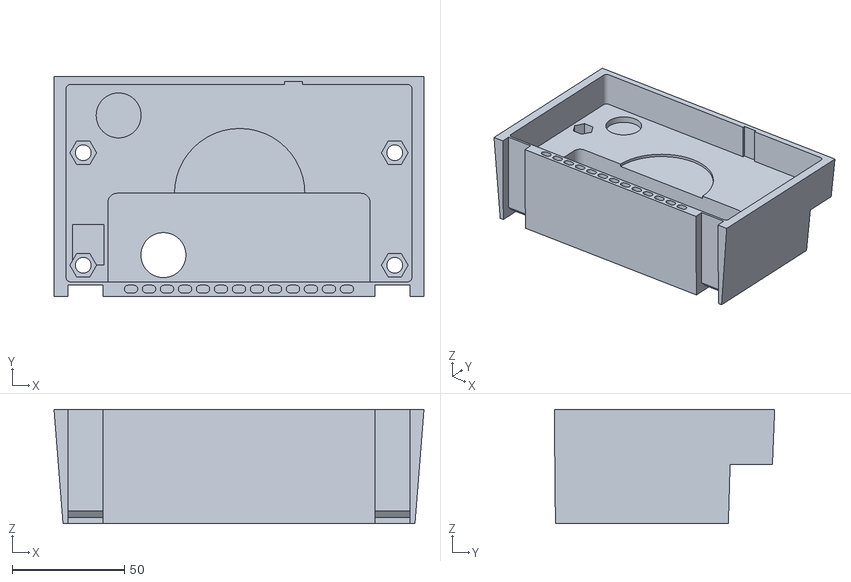
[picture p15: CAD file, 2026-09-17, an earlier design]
src/stl/v0.2/otr620_insert.stl
164.5 x 98.0 x 50.8

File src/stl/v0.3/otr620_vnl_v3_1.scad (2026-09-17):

// V3.1 PROTOTYPE — dimensions inherited unless noted. Read README before printing.
// Garmin dezl OTR620 flush dash insert + hanging shelf  (v2)
// 2022 Volvo VNL 860 upper dash cubby
//
// v2: pocket sized for 1 mm rubber pads (removable friction fit), hanging shelf for
//     AirPods Pro 3 (Latercase) at 45 deg + MagSafe PopGrip seat, shelf locked in by
//     tongues that run under the insert and are clamped by the two bottom bolts.
//
// Units: mm. Design space: X = across (0 = left edge as the driver sees it),
// Y = up (0 = cubby floor), Z = depth (0 = front face, + goes into the dash).
// Printable solids get mirrored once so they come out with the right handedness.
//
// Export (Linux):
//   openscad -D 'part="insert"'      -o otr620_insert.stl             otr620_vnl_insert.scad
//   openscad -D 'part="shelf"'       -o otr620_shelf.stl              otr620_vnl_insert.scad
//   openscad -D 'part="fit_frame"'   -o fit_test_1_face_frame.stl     otr620_vnl_insert.scad
//   openscad -D 'part="fit_gauge"'   -o fit_test_2_depth_gauges.stl   otr620_vnl_insert.scad
//   openscad -D 'part="bolt_test"'   -o fit_test_3_bolt_trap.stl      otr620_vnl_insert.scad
//   openscad -D 'part="pocket_test"' -o fit_test_4_shelf_pockets.stl  otr620_vnl_insert.scad

part = "assembly"; // [assembly, insert_v3, bezel_v3, shelf_v3, fit_frame, fit_gauge, bolt_test, accessory_test, usb_test, nut_test, bolt_cover_test, pad_test, led_carrier]

/* [Cubby: your measurements] */
open_w  = 165.1;  // 6-1/2"  opening width at the front edge
open_h  = 98.4;   // 3-7/8"  cubby floor (top of front lip) to top of opening
low_h   = 79.4;   // 3-1/8"  floor to underside of the top bar
cubby_d = 50.8;   // 2"      front edge to back wall below the bar
bar_d   = 25.4;   // 1"      front edge to the face of the top bar

/* [Fit and draft] */
fit_side   = 0.30; // gap per side at the front edge
fit_top    = 0.40; // gap at the top edge
bar_gap    = 1.00; // gap to the face of the bar
low_gap    = 0.50; // gap under the bar
draft_side = 4.0;  // each side wall steps in this much at full depth (cubby walls taper)
draft_top  = 1.0;  // ceiling drops this much over the bar depth
draft_low  = 1.5;  // bar underside drops this much toward the back
draft_bot  = 0.5;  // floor rises this much toward the back

/* [GPS: dezl OTR620] */
gps_w  = 152.4;  // 6.0"
gps_h  = 86.4;   // 3.4"
gps_t  = 18.0;   // MEASURE YOUR UNIT (listings say 0.7" / 1.8 cm / 1.9 cm)
gps_r  = 2.0;    // pocket corner radius (device is ~2.3)
chin_h = 6.6;    // face below the screen, carries the speaker grille

/* [GPS retention] */
use_pads    = true; // true: rubber pads on walls + floor. false: VHB tape on the floor
pad_t       = 1.0;  // rubber pad thickness
pad_squeeze = 0.3;  // how much each wall pad gets compressed
fit_tape    = 0.5;  // gap per side when using tape instead of pads
tape_t      = 1.1;  // tape thickness (3M 5952 VHB = 1.1)

/* [Back-of-GPS features, front view, mm from GPS left edge / top edge] */
pwr   = [22.7, 13.1];  // power key (on the back!)
usb   = [42.6, 75.2];  // USB-C port (on the back, plug points straight back)
sd    = [ 9.1, 70.6];  // microSD slot
mnt   = [76.5, 47.9];  // mount socket recess
mic_x = 100.4;         // microphone hole on the top edge

/* [Bolts] */
bolt_d    = 7.0;           // channel, passes a 1/4" drill bit
head_af   = 9.9;          // hex trap across flats: fits 3/8" and 10 mm heads
seat_back = 12.0;          // from bolt-head seat to the back face (includes shelf tab)
bolt_x    = 13.0;          // channel centre from each side of the face
bolt_y    = [14.0, 64.0];  // channel heights above the floor (both below the bar)

/* [Speaker duct, grille, cable] */
win_x    = 24.0;  // duct window starts this far in from each side
win_top  = 46.0;  // top of the duct window (height above floor)
back_t   = 2.0;   // back plate that closes the duct
cable_d  = 20.0;  // cable pass-through in back plate, behind the USB-C port
bot_wall = 1.7;   // plastic under the grille slots
lip_t    = 1.5;   // plastic between grille slots and GPS
slot_l   = 6.0;
slot_rib = 2.0;
slot_n   = 13;
mic_w    = 8.0;
mic_dp   = 1.2;
pwr_relief_d  = 20.0;
pwr_relief_dp = 3.5;

/* [Shelf] */
shelf      = false;  // hanging shelf + its tongue channels in the insert
items_swap = false; // false: PopGrip on the left (driver side), AirPods on the right
shelf_gap  = 1.0;   // clearance between the shelf back and the trim below the cubby
rail_d     = 8.0;   // depth of the rail that sits against the bottom of the face
rail_top   = 1.5;   // rail height on the face (stays below the grille slots)
tongue_x   = 6.5;   // tongues start this far in from each side
tongue_w   = 15.0;
tongue_t   = 5.0;
tab_t      = 2.5;   // L-tab behind the insert; the bottom bolts pass through it
tab_h      = 24.0;

/* [AirPods Pro 3 in Latercase] */
ap_w     = 63.4;  // 62.2 case + 2 x 0.6 Latercase
ap_d     = 23.0;  // 21.8 + 1.2
ap_h     = 48.4;  // 47.2 + 1.2
ap_fit   = 0.4;   // gap per side in the socket
ap_depth = 30.0;  // how much of the case sits inside the socket
ap_wall  = 2.5;
ap_shift = 2.0;   // socket sits this far further down the slope than the PopGrip seat

/* [MagSafe PopGrip] */
pop_shape = "round"; // [round, oval]  round = current MagSafe PopGrip, oval = 2021 original
pop_d     = 57.9;    // round base diameter (2.28")
pop_ow    = 56.9;    // oval base width
pop_ol    = 90.0;    // oval base length
pop_fit   = 1.6;     // total clearance across the seat
pop_depth = 3.0;     // seat recess depth (stick a MagSafe metal ring on its floor)

$fn = 48;

// ---------- derived ----------
FIT     = use_pads ? pad_t - pad_squeeze : fit_tape;
FLOOR_T = use_pads ? pad_t : tape_t;
FW = open_w - 2*fit_side;
FH = open_h - fit_top;
LH = low_h - low_gap;
D  = cubby_d;
BD = bar_d - bar_gap;
PW = gps_w + 2*FIT;
PH = gps_h + 2*FIT;
PD = gps_t + FLOOR_T;
px0 = (FW - PW)/2;
py0 = chin_h;
gy0 = bot_wall;
gy1 = py0 - lip_t;
slot_h = gy1 - gy0;
z0  = gps_t + (py0 - gy0) + 0.8;      // duct roof depth at slot bottom (45 deg roof)
pitch = slot_l + slot_rib;
grille_w = slot_n*pitch - slot_rib;
trap_r = head_af/sqrt(3);             // hex circumradius

function gx(fx) = px0 + FIT + fx;
function gy(fy) = py0 + FIT + gps_h - fy;
function ds(z) = draft_side*z/D;
function db(z) = draft_bot*z/D;

// shelf geometry, 2D points are [y, z]
S2 = sqrt(2)/2;
W2 = [S2,  S2];   // up the 45 deg slope (toward the dash)
U2 = [S2, -S2];   // out of the slope (toward the driver)
pop_seat_w = (pop_shape == "round") ? pop_d + pop_fit : pop_ow + pop_fit;  // along slope
pop_seat_x = (pop_shape == "round") ? pop_d + pop_fit : pop_ol + pop_fit;  // across
seat_rim   = 1.75;
slope_top  = [rail_top - 0.4, -rail_d];
s_c        = 3.5 + pop_seat_w/2;
slope_len  = s_c + pop_seat_w/2 + seat_rim;
M_pop = slope_top - s_c*W2;
M_ap  = slope_top - (s_c + ap_shift)*W2;
S_bot = slope_top - slope_len*W2;
ap_sw = ap_w + 2*ap_fit;
ap_hw = (ap_d + 2*ap_fit)/2;
F_out = M_ap - (ap_depth + ap_wall)*U2;
C_low = F_out - (ap_hw + ap_wall)*W2;
y_bot = C_low[0];
k_b   = F_out[0] - F_out[1];            // shelf underside line: y = z + k_b
shelf_profile = [
    [rail_top, 0], [rail_top, -rail_d], slope_top, S_bot,
    [y_bot, S_bot[1]], [y_bot, y_bot - k_b],
    [k_b - shelf_gap, -shelf_gap], [-shelf_gap, -shelf_gap], [0, 0]   // 45 deg step: no support needed
];
ap_ow    = ap_sw + 2*ap_wall;
pop_ow_x = pop_seat_x + 2*seat_rim;
gap_items = max(0, min(6, FW - ap_ow - pop_ow_x - 2));
row_w  = ap_ow + gap_items + pop_ow_x;
row_x0 = (FW - row_w)/2;
pop_cx = items_swap ? row_x0 + ap_ow + gap_items + pop_ow_x/2 : row_x0 + pop_ow_x/2;
ap_cx  = items_swap ? row_x0 + ap_ow/2 : row_x0 + pop_ow_x + gap_items + ap_ow/2;
ap_top_pt   = M_ap + (ap_h - ap_depth)*U2 + ap_hw*W2;          // highest point of the case
ap_back_pt  = M_ap - ap_depth*U2 + ap_hw*W2;                   // deepest socket corner
tongue_x0 = [tongue_x, FW - tongue_x - tongue_w];
tongue_bx = [bolt_x, FW - bolt_x];
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

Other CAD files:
src/stl/v0.1/fit_test_1_face_frame.stl
src/stl/v0.2/otr620_shelf.stl
src/stl/v0.2/fit_test_1_face_frame.stl
src/stl/v0.1/otr620_vnl_insert.scad
src/stl/v0.2/otr620_vnl_insert.scad
src/stl/v0.1/fit_test_3_bolt_trap.stl
src/stl/v0.2/fit_test_3_bolt_trap.stl
src/stl/v0.2/fit_test_4_shelf_pockets.stl

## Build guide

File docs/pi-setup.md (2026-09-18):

# Pi setup and implementation plan

[Project](../README.md) · [Tasks](todo.md) · [V3.1 print notes](../src/stl/v0.3/README.md)

Status: **simulation software implemented; hardware integration pending**. The earlier review of commit `f8075d72dddf59a85583dda3cea287938e356ffc` found no `src/pi/` directory and withdrew incomplete README snippets. The first package now implements deterministic fan/LED decisions, fault handling, configuration, console status and tests. It has no physical outputs or live sensor reads. No v0.4 CAD has been generated. See [running instructions](../src/pi/README.md).

## Decisions and outstanding choices

- Selected fan: **Noctua NF-A4x20 5V PWM**, four-pin, with temperature-based speed control and a manual override.
- Selected host: **Raspberry Pi Zero 2 W with Raspberry Pi OS Lite**, confirmed by the user for full Linux services and low-level peripheral control. A Pico is not required for the initial design.
- Keep the Garmin on its supplied power arrangement for initial tests. The Pi supervises accessories; a rated power-distribution circuit supplies their current.
- The Pi Zero 2 W is selected. Choose the exact OLED module, switches, regulator and GNSS receiver before freezing pin assignments and enclosure cutouts.
- The user is printing the four v0.2 test pieces. Printing has started; no physical fit result is recorded yet.

The Zero 2 W uses micro-USB connectors and 2.4 GHz Wi-Fi. A USB-C panel inlet would therefore be part of the mount's power design, not the Pi's native connector. Confirm the truck network supports the board and include adapter/cable space in CAD. [Raspberry Pi specifications](https://www.raspberrypi.com/products/raspberry-pi-zero-2-w/)

## Selected fan and proposed interface

| Item | Manufacturer specification |
|---|---|
| Model | NF-A4x20 5V PWM |
| Body / with pads | 40 × 40 × 20 mm / 40 × 40 × 22 mm |
| Mounting-hole spacing | 32 × 32 mm |
| Supply / maximum current | 5 V / 0.1 A |
| Connector | Four-pin |
| Speed at 0% PWM | Stopped |

Source: [Noctua model specifications](https://www.noctua.at/en/products/nf-a4x20-5v-pwm/specifications). Confirm dimensions on the actual part. A 22 mm body envelope is not sufficient evidence for a 22 mm printed pocket: add fit tolerance, connector access, wire bends, mounts and unobstructed intake/exhaust space. The current lower cavity is about 29.8 mm deep and the sound opening about 39.4 mm high; installation needs a geometry review.

| Fan pin | Manufacturer wire colour | Proposed connection |
|---|---|---|
| 1 | Black | Common ground |
| 2 | Yellow | Protected, regulated 5 V fan branch |
| 3 | Green | Optional tachometer input with a suitable 3.3 V pull-up/interface |
| 4 | Blue | Dedicated PWM control interface; never join to the ground conductor |

Verify connector orientation and pin numbers, especially with adapters. The manufacturer's colours supersede the older README's red supply-wire label. Fan power must not come from a GPIO output.

Use a **25 kHz target** with the manufacturer's allowed **21–28 kHz** range. Noctua describes an internal PWM pull-up, recommends a CMOS-style driver and does not recommend an open-collector driver for its fans. Select a Pi-compatible interface after checking the actual fan's pull-up voltage and powered/unpowered conditions; direct GPIO compatibility is not established by the old drawing. With no PWM input, the fan runs at full speed, but a crashed output held low may instead leave it stopped. Design and test fault handling accordingly. [Noctua PWM white paper](https://noctua.at/pub/media/wysiwyg/Noctua_PWM_specifications_white_paper.pdf)

GPIO18 is a candidate signal pin, not a finalized wiring instruction. `RPi.GPIO.PWM()` produces software PWM; using GPIO18 does not automatically select hardware PWM. Choose and verify a hardware PWM backend for the selected board/OS, or use a dedicated controller. [RPi.GPIO project documentation](https://pypi.org/project/RPi.GPIO/)

## Review findings to resolve in implementation

| Finding in the previous examples | Required behavior |
|---|---|
| Missing sensor returns an empty string and the caller indexes it | Return a typed fault; survive missing files, disconnects and malformed data. |
| CRC retry loop has no deadline | Bound retries and stale-reading age; controller ticks must keep running. |
| Missing temperature marker becomes 0°C | Do not interpret errors as a cold compartment. Enter a documented fallback state. |
| First discovered sensor is used without identity | Configure sensor IDs and distinguish GPS compartment, charger and Pi CPU readings. |
| Software PWM is labelled hardware PWM | Verify waveform frequency and duty under CPU/network load. |
| OLED uses fixed fan/GPS/LED values | Read shared controller state; distinguish requested duty, measured RPM and unavailable feedback. |
| Network subprocesses have no timeout | Bound calls and keep display/network failures independent of thermal control. |
| Abrupt master power-off is assumed | Define shutdown request, power-hold hardware and restart behavior before connecting ignition control. |
| GPS data source is unspecified | Verify a usable live Garmin interface or select a supported external GNSS receiver. |

On temperature-sensor failure, the simulation requests full cooling and reports a fault; a future hardware adapter must apply that request while the fan branch is powered. This software policy cannot guarantee cooling during a power failure or a crashed GPIO driver; bench-test the electrical default state. The implemented simulation permits auto or full-speed boost; sensor faults take priority. A force-off mode is not provided. Validate the policy with the physical hardware before use.

The earlier 35–45°C ramp is a **bench starting proposal**, not a validated protection limit. Simulation uses 35°C start, 32°C stop and a provisional 30% minimum request. Startup behavior and minimum stable duty still need physical calibration. Calibrate against actual sensor placement and the GPS/charger operating limits. A housing sensor does not measure the device's internal battery temperature.

## Software status under src/pi

Run the package with Python 3.11+; no GPIO libraries are imported. The only supported mode is `simulate`.

```sh
cd src/pi
python3 -m truck_gps --config config.example.toml --format json
python3 -m unittest discover -s tests -v
```

| File | Implemented now | Remaining hardware work |
|---|---|---|
| `README.md`, `pyproject.toml` | Quickstart and installable CLI, no external runtime dependencies | Verify on the actual Pi OS/Python |
| `config.example.toml`, `truck_gps/config.py` | Validated thresholds, expected sensor ID and LED settings | Pin/interface configuration after hardware selection |
| `truck_gps/sensors.py` | Pure captured 1-Wire sample parser and typed faults | Identified device reads with bounded acquisition |
| `truck_gps/hardware.py` | Simulation output adapter only | Verified PWM/GPIO adapters, boot/crash behavior |
| `truck_gps/controller.py` | Fan curve/hysteresis, auto/boost, LED requests and fault priority | Startup kick/minimum-duty calibration and buttons |
| `truck_gps/display.py` | Text/JSON status; RPM and GPS power explicitly unknown | OLED renderer, bounded network status |
| `truck_gps/main.py`, `truck_gps/simulation.py` | Validated scenarios, virtual time, logging and signal handling | Live acquisition/control scheduling |
| `systemd/truck-gps-sim.service` | Optional simulation-only template denying device access | Actual Pi installation and production service permissions |
| `tests/` | 21 passing software tests, including CLI/SIGTERM | Physical sensor/fan/output and Pi boot tests |

The demo runs immediately by default; `--realtime --loop` paces a repeating scenario. It does not run a real temperature acquisition loop. Scenario timestamps are virtual. A hardware service must use actual monotonic sample times and keep reads, display/network operations and control scheduling independent.

Keep the control loop local and independent of Tailscale, maps, OLED and internet availability. Use a Python virtual environment and a service account with only the needed device permissions. Keep credentials outside the repository. Read [the package documentation](../src/pi/README.md) for configuration, fault recovery and service-template limitations.

## Bring-up sequence when the Pi arrives

1. Use Raspberry Pi Imager to install an OS Lite image supported by the selected board. Configure hostname, user, Wi-Fi country/network and SSH access. Boot on a suitable bench supply. [Official setup guide](https://www.raspberrypi.com/documentation/computers/getting-started.html)
2. Update the OS, record its version and establish SSH. Install Tailscale using its current Linux instructions and verify access from an authorized device. [Tailscale installation](https://tailscale.com/docs/install/linux)
3. Enable I²C and 1-Wire using the selected OS configuration tools. Test the identified temperature sensor and exact OLED module separately. Match SSD1306 versus SH1106 drivers and verify supply and pull-up voltages. [Pi configuration guide](https://www.raspberrypi.com/documentation/computers/configuration.html)
4. Run the existing package and simulation tests on the Pi; record the OS/Python versions. Freeze board/OS-specific GPIO dependencies only after verifying support.
5. Implement live sensor acquisition and the hardware adapter. With the selected PWM interface and protected fan supply, test commanded duty, startup, stopping, optional tach feedback and sensor disconnection. Verify timing under load.
6. Add dim LEDs and debounced buttons. Verify that accessory switching does not interrupt the Garmin branch.
7. Add the service and test reboot, service crash, missing OLED, Wi-Fi loss and controlled shutdown. Do not rely on service restarts alone as the fan's electrical fallback.
8. Add GNSS logging and the home map later. Validate no-fix/stale-fix handling, trip distance, year boundaries and storage retention before adding traffic APIs. Keep trip data usable during network outages.

## v0.4 preparation after fit tests

Use `src/stl/v0.4/` for the next mechanical revision once inputs are available; it does not exist yet. Preserve the older session files.

- Record v0.2 face-frame, depth-gauge, bolt-trap and shelf-pocket results. The round v0.2 PopGrip seat does not validate the oval accessory.
- Test the v0.3 faceplate tabs and M2 nut pockets separately.
- Confirm the cubby measurement starts at the top of the black floor lip; measure taper, corners and shelf/control clearance.
- Measure the chosen electronics, switches, fan, connectors and cable bends. Keep GPS-dependent geometry provisional until the unit arrives.
- Design a removable electronics carrier, adjustable fan mount, separate ventilation path, serviceable wiring and modular display/switch cutouts.
- Maintain the padded GPS support, removable faceplate, speaker path and upward-facing accessory tray.
- Print new local fit coupons before exporting the complete v0.4 assembly. Check bed footprint, supports and interfaces again.

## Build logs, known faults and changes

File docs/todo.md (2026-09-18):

# OTR620 & Truck GPS Master Plan

[Current design](../README.md) · [V3.1 print instructions](../src/stl/v0.3/README.md) · [Conversation archive](chats.md) · [TomTom API](tomtom-api.md) · [Google Maps API](google-maps-api.md)

Baseline: **V3.1 fit prototype**, September 17, 2026. Checked items reflect work recorded in the session. Unchecked items have no recorded completion. Electrical values and unmeasured fit dimensions are provisional. No deadlines have been agreed.

---

## Completed design and documentation work

- [x] Review the supplied v2 source, six STL files and seven photos.
- [x] Identify the oval PopSocket mismatch, friction-only GPS retention and missing cable strain relief.
- [x] Create the V3 padded cradle, gasketed removable faceplate, upward-facing 45° AirPods tray and oval PopSocket pocket.
- [x] Enlarge the rear USB opening and add provisional cable-tie slots.
- [x] Update to V3.1 with four M2 × 6 mm screws and plain M2 nuts in the fixed bracket tabs.
- [x] Include nut-fit coupons and truck/accessory fit tests in the 12-STL package.
- [x] Record basic mesh-edge checks and nominal 220 × 220 mm bed checks, including a 10 mm brim allowance per side.
- [x] Record a faceplate clearance check with intended contact surfaces slightly separated.
- [x] Document the staged power, lighting, charging and cooling concepts.
- [x] Create the Word project record and split it into README.md, chats.md and todo.md.
- [x] Convert Google Maps and TomTom API PDF specifications into standard markdown (`docs/google-maps-api.md`, `docs/tomtom-api.md`) and clean up PDFs.
- [x] Restructure and rename repository to `truck-gps` and map future source code to `src/pi/` and 3D printing components to `src/stl/`.

---

## 1. Truck and accessory tests — next work

**In progress:** the user is printing the four v0.2 test files. Do not mark fit validation complete until results are recorded. The v0.3 tab/nut tests remain separate.

Goal: verify the truck and accessories before committing to the full print; the GPS is not required for these steps.

- [ ] Confirm filament, nozzle diameter and slicer profile for the Ender 3 Neo.
- [ ] Select the final dashboard material based on printer capability and heat performance; keep mockup and final-material results distinct.
- [ ] Inspect each test in the slicer at 100% scale; check clips, exclusion zones, purge lines, support footprint and brim clearance.
- [ ] Remeasure opening height from the cubby floor/top of the black front lip to the opening top; record lip height separately from gray trim. The earlier approximately 8 mm discrepancy was a photo estimate.
- [ ] Print `src/stl/v0.3/truck_fit_frame.stl`; check opening, corner radii, floor ridges and trim behind the wider mounting tabs.
- [ ] Print `src/stl/v0.3/fit_gauge.stl`; check depth, taper and the top-bar step against the stated 25.4/50.8 mm depths.
- [ ] Determine whether to remove the existing ball mount or revise geometry to clear it.
- [ ] Print `src/stl/v0.3/dash_bolt_test.stl`; measure actual dash bolts and confirm head/shank fit, rear access and installation hardware. These are separate from the small M2 faceplate screws.
- [ ] Print `src/stl/v0.3/nut_fit_test.stl` and `src/stl/v0.3/bolt_cover_test.stl`; compare 4.1/4.3/4.5 mm nut allowances with actual hardware.
- [ ] Verify screw reach and repeated faceplate removal; settle how nuts remain in the open loading slots when screws are absent.
- [ ] Measure rubber thickness including adhesive and its compressed thickness; test `src/stl/v0.3/pad_test.stl` with a measured 20 mm block.
- [ ] Test adhesive compatibility with the rubber and chosen print material.
- [ ] Print `src/stl/v0.3/accessory_test.stl` with the Latercase installed; measure AirPods case-on width, height and depth, and PopSocket length, width and thickness.
- [ ] Check the shelf reach with a cardboard profile: approximately 80.1 mm forward and 73.9 mm below the cubby.
- [ ] Record photos and measured tight/loose areas, then revise CAD parameters and reprint affected coupons.

---

## 2. GPS verification — when the unit arrives

- [ ] Measure the OTR620 housing and compare it with the 152.4 × 86.4 × 18 mm stand-in; verify the older approximately 2.3 mm device-radius and 2.0 mm pocket-radius assumptions.
- [ ] Verify that the complete GPS/padding arrangement remains ahead of the top bar, including rear features and cable clearance.
- [ ] Photograph the rear square-on with a ruler; locate USB-C, speaker, microphone, power button and microSD access.
- [ ] Measure the plastic bezel and verify the 1.2 mm faceplate overlap stays clear of display glass.
- [ ] Confirm the required rubber compression and closure stops; avoid clamping the glass or distorting the housing.
- [ ] Choose a replaceable silicone gasket or compatible gasket-maker process; test the 1.2 × 0.6 mm groove. Fully cure formed gasket material away from the GPS.
- [ ] Measure the right-angle cable while plugged in: rear projection, sideways reach, strain-relief envelope and exit direction.
- [ ] Resolve the older 20 mm versus 3/4-inch cable-hole wording: 3/4 inch equals 19.05 mm. Size the opening for the actual connector and any selected protection.
- [ ] Confirm the cable route through or behind the cubby; the current insert uses the nominal full 50.8 mm depth.
- [ ] Revise the USB clearance pocket and add a removable cable-jacket clamp if needed, keeping slack at the connector.
- [ ] Read GPS/adapter labels and verify operating voltage and charging demand with navigation running and a partly discharged battery. Do not adopt 5 V/1 A as a confirmed rating.

---

## 3. Mechanical assembly and validation

- [ ] Recheck thin sections near tongue channels and rear microphone routing before adding holes, latch roots or electronics mounts.
- [ ] Slice `src/stl/v0.3/insert.stl`, `src/stl/v0.3/faceplate.stl` and `src/stl/v0.3/shelf.stl`; inspect the insert step, nut tabs, tongues, supports and print orientation.
- [ ] Assemble using measured dash hardware and tested M2 fasteners; verify the lower bolts clamp the shelf tongues/L-tabs as intended.
- [ ] Confirm the 176.5 mm tab width and 6.6 mm faceplate projection plus screw heads clear the actual dashboard.
- [ ] Confirm comfortable GPS insertion/removal and repeatable screw/nut service without excessive pad compression.
- [ ] Check AirPods lid opening, retrieval, upward-facing orientation and future charging-cable access.
- [ ] Compare rear-speaker sound with and without the return duct; check for muffling and rattles.
- [ ] Verify microphone, controls, SD access, GPS reception and charging while stationary.
- [ ] Evaluate retention, fastener loosening, pad creep and thermal deformation before relying on the assembly during normal driving.
- [ ] Revise and export affected parts; update CAD check results for the revision actually being printed.

---

## 4. Power & Front Bracket Switches Planning

- [ ] Finalize power strategy: evaluate Single USB-C PD Input (using 9V or 12V PD contract stepped down to 5V @ 4A with internal buck converter) vs. Dual USB-C Input (independent cables for GPS and auxiliary boards).
- [ ] Design the front switch/button layout on the bracket to house four physical power control toggles:
  1. **Master Power** (isolates the whole system).
  2. **GPS Power** (enables/disables Garmin OTR620 supply).
  3. **Blue LEDs Power** (manual control of ambient bracket lighting).
  4. **Cooling Fan Power** (manual override / auto toggle for compartment fan).
- [ ] Select appropriate panel-mount miniature toggle or tactile push buttons matching the front depth and width clearances.
- [ ] Define controlled shutdown and power-hold hardware before enabling ignition or master power cutoff on the Linux Pi.
- [ ] Recalculate combined power demand with the selected Pi and all peripherals; the previous 5 V/4 A allowance is not a verified system rating.
- [ ] Keep initial Garmin power separate and prevent accessory/controller resets from interrupting it.
- [ ] Ensure power wiring route stays clear of the speaker duct and mechanical stress points during faceplate removal.

---

## 5. Telemetry & Web Tracking System

Goal: leverage the in-truck Starlink Wi-Fi network and a private VPN overlay to track physical coordinates and display them on a real-time map at home.

- [x] Select **Raspberry Pi Zero 2 W with Raspberry Pi OS Lite** for Linux services plus local peripheral control.
- [ ] Select and verify the board/OS-specific GPIO and hardware PWM backend; configure I²C and 1-Wire for the chosen peripherals.
- [ ] Install **Tailscale** on the selected in-cab Pi; verify connection through the truck's Starlink Wi-Fi.
- [ ] Select and bench-test a GNSS receiver or verify a usable live Garmin interface; do not assume the OTR620 exports NMEA.
- [ ] Write a telemetry background service under `src/pi/` to:
  * Read NMEA GPS data from a connected GPS receiver module.
  * Keep track of cumulative km/miles travelled for the calendar year.
  * Maintain a local JSON database logging states, provinces, and countries visited.
- [ ] Develop a lightweight web dashboard under `src/pi/` (using Python FastAPI/Flask) that:
  * Serves a real-time interactive map showing the truck's current position.
  * Connects to map and traffic engines on free tiers (see [docs/tomtom-api.md](tomtom-api.md) and [docs/google-maps-api.md](google-maps-api.md)).
  * Overlays real-time traffic updates from TomTom Orbis Traffic API on the route.
- [ ] Setup the Home Display System:
  * Configure a secondary Raspberry Pi connected via HDMI to a television or small monitor at home.
  * Install Tailscale on the Home Pi.
  * Configure the Home Pi to boot directly into a browser loading the in-cab Pi's private Tailscale IP webpage (e.g., `http://100.x.y.z/map`).
  * Verify live telemetry reporting and automatic page refreshes.

---

## 6. Modular lighting and wired charging

- [ ] Select two diffused blue LEDs, one resistor per LED, and wire them to the dedicated front button on the faceplate.
- [ ] Test `src/stl/v0.3/led_carrier.stl`; aim LEDs at an internal surface and keep wiring clear of the sound path.
- [ ] Select a suitable shelf USB-C output and short approximately 0.5 ft angled USB-C cable for wired AirPods charging.
- [ ] Check connector access and bend clearance with the Latercase installed and AirPods in the tray.
- [ ] Verify simultaneous GPS and AirPods charging under the expected load and temperature conditions.

---

## 7. Optional wireless charging

- [ ] Select a complete compatible charging puck and test it through the Latercase before designing its recess in the shelf.
- [ ] Check alignment, charging stability and temperature with the case at the intended 45° angle.
- [ ] Design a removable puck backing with minimal extra plastic between charger and case.
- [ ] Verify the charger cable remains accessible and the holder still supports easy AirPods removal.

---

## 8. Selected fan and thermal control

- [x] Select the **Noctua NF-A4x20 5V PWM**, four-pin fan, per the user's preference.
- [ ] Measure the actual fan and verify the [manufacturer dimensions and connection plan](pi-setup.md#selected-fan-and-proposed-interface).
- [ ] Design a removable v0.4 mount with clearance beyond the padded fan envelope, including wiring, fasteners and airflow. Do not assume a 22 mm pocket is sufficient.
- [ ] Verify mounting hardware and the complete fit against the GPS, USB elbow, controller and current cavity.
- [ ] Add top exhaust and lower intake vents with a separate path from the sound duct; check cabin-air access and acoustic effects.
- [ ] Select and identify the DS18B20 sensors; verify power, pull-ups, placement and cable routing.
- [ ] Implement bounded reads, CRC/format validation, stale-data detection and sensor-fault reporting.
- [ ] Choose a hardware PWM backend compatible with the selected Pi/OS and verify 25 kHz timing under load. `RPi.GPIO.PWM()` is not hardware PWM.
- [ ] Replace the previous direct-wiring assumption with a verified Pi-compatible PWM interface and protected fan power branch; confirm connector pin numbering.
- [ ] Configure hysteresis, startup/minimum duty and manual override. Treat the earlier 35–45°C ramp as a provisional bench setting.
- [ ] Test sensor disconnects, a stuck/crashed output, reboot and supply loss. Software requesting full cooling cannot guarantee cooling after loss of power or control hardware.
- [ ] Add optional tach feedback; distinguish requested duty from measured speed.
- [ ] Deploy the hardware-enabled controller and production service on the Pi after bench validation; the simulation package and service example are implemented below.

---

### First software milestone — simulation complete

- [x] Add a Python 3.11+ package and CLI with no external runtime dependencies.
- [x] Implement automatic fan curve/hysteresis, full-speed boost and LED switch/brightness decisions.
- [x] Parse captured 1-Wire samples and request full cooling for missing, invalid, wrong-ID or stale readings.
- [x] Keep requested outputs separate from unknown RPM and GPS power feedback.
- [x] Add validated TOML settings, JSON scenarios, text/JSON output and clean signal handling.
- [x] Pass 21 software tests covering control boundaries, faults, recovery, restart state, input validation and CLI behavior.
- [x] Include a simulation-only systemd example; physical installation remains pending.
- [ ] Run the package on the actual Pi OS and record versions and results.
- [ ] Add bounded live sensor acquisition, verified fan/LED outputs and debounced physical buttons.
- [ ] Calibrate physical startup/minimum fan duty and test electrical fallback independently of software.

## 9. Status Display & Dashboard HUD (I2C OLED)

- [ ] Select and size the **SSD1306/SH1106 I2C OLED display**:
  - Choose between a 0.96" (smaller, standard) or 1.3" (highly readable) 128x64 display panel.
  - Verify that the display uses standard 4-pin I2C connectors (VCC, GND, SCL, SDA).
- [ ] Model the **display bezel & mount** on the bracket front:
  - Create a precise rectangular cutout on the front faceplate for the OLED screen area.
  - Design internal mounting points (screw bosses or slide-in clips) on the rear of the faceplate to secure the display securely against the window.
  - Route the I2C wires cleanly behind the display to prevent interference with the sound duct or AirPods tray.
- [ ] Wire the screen to the Pi:
  - Connect **VCC** directly to **Pi 3.3V (Pin 1)** to match logic levels.
  - Connect **GND** directly to **Pi Ground (Pin 9)**.
  - Connect **SDA** to **GPIO 2 (Pin 3)** and **SCL** to **GPIO 3 (Pin 5)**.
- [ ] Configure and test the Display Software on the Pi OS:
  - Enable the I2C interface via `sudo raspi-config` or adding `dtparam=i2c_arm=on` to `/boot/firmware/config.txt`.
  - Verify address detection via `i2cdetect -y 1` (default address should be `0x3C` or `0x3D`).
  - Install tested dependencies in the application virtual environment; select the driver for the actual OLED controller.
  - Deploy the in-cab display monitor python daemon script under `src/pi/`.
  - Hook up system queries inside the script to fetch the current Starlink Wi-Fi SSID, local IP address, and Tailscale VPN status.
  - Integrate variables from the fan controller and physical buttons threads to dynamically update fan speed percentages and switch statuses (GPS/LEDs) on the screen.
  - Report actual shared state; do not use fixed fan/switch values or label Pi CPU temperature as compartment temperature.
  - Bound network queries and keep display faults independent of fan control.
  - Set the script to boot on startup as a persistent `systemd` system service.

---

## 10. Repository and archive maintenance

- [x] Confirm access to [nuniesmith/truck-gps](https://github.com/nuniesmith/truck-gps) through the GitHub connection.
- [x] Verify the three model directories under `src/stl/` and the V3.1 source, 12 STLs, hardware image and mesh report under `src/stl/v0.3/`.
- [x] Preserve the supplied Claude v0.1/v0.2 responses and available ChatGPT discussion in `docs/chats.md`.
- [x] Preserve the newer telemetry, cooling and OLED plans while reconciling documentation links and current session paths.
- [x] Create the first `src/pi/` controller package with simulation, validated settings, fault reporting and CLI tests.
- [ ] Implement and bench-test live sensor, GPIO/PWM, button and OLED adapters before enabling hardware control.
- [ ] If any original Claude prompts, code blocks or turns are missing from the supplied text, append them with their session labels.
- [ ] Update the mechanical source, exported files and print notes together after measured fit changes.

## 11. v0.4 preparation after test prints

- [ ] Record all four v0.2 fit results and photograph interference points; measure the floor-lip reference, corners, taper and shelf clearance.
- [ ] Validate the v0.3 front tabs and M2 coupons plus the oval PopSocket geometry.
- [ ] Confirm actual Pi, fan, OLED, buttons, power hardware and cable envelopes before fixing cutouts.
- [ ] Create `src/stl/v0.4/` from the accepted dimensions, preserving prior revisions.
- [ ] Add a removable electronics carrier, fan bracket, separate vents, serviceable wiring and modular display/switch openings.
- [ ] Keep GPS-dependent fits provisional until the device arrives; validate local coupons before the complete assembly.

## Fit result record

Copy this table for each test or revision. Blank cells indicate information still to record.

| Field | Result |
|---|---|
| Date / CAD revision / test part | |
| Printer / filament / nozzle | |
| Layer height / walls / orientation / supports | |
| Actual hardware or accessory used | |
| Measured dimensions / fit gaps | |
| Tight or interfering locations | |
| Photos / observations | |
| Required CAD change | |
| Retest outcome | |

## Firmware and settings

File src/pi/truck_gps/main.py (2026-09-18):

"""Command line demonstration; hardware mode cannot be enabled."""

import argparse
import logging
from pathlib import Path
import signal
import threading

from .config import load_config, number, percentage
from .controller import Controller
from .display import render_json, render_text
from .hardware import SimulatedOutputs
from .simulation import load_scenario, reading_from_row

LOG = logging.getLogger("truck_gps")


def main(argv: list[str] | None = None) -> int:
    parser = argparse.ArgumentParser(description="Truck GPS accessory simulation — no hardware outputs")
    parser.add_argument("--mode", choices=["simulate"], default="simulate")
    parser.add_argument("--config", type=Path)
    parser.add_argument("--scenario", type=Path, help="JSON scenario; defaults to the built-in demo")
    parser.add_argument("--format", choices=["text", "json"], default="text")
    parser.add_argument("--fan-mode", choices=["auto", "boost"], default="auto", help="initial mode; scenario events can change it")
    parser.add_argument("--led-brightness", type=float, help="initial setting; does not enable the LEDs")
    parser.add_argument("--led-on", action="store_true", help="initially enable LEDs")
    parser.add_argument("--interval", type=float, default=5.0, help="virtual seconds per sample")
    parser.add_argument("--realtime", action="store_true", help="pace samples in wall-clock time")
    parser.add_argument("--loop", action="store_true", help="repeat scenario; requires --realtime")
    args = parser.parse_args(argv)
    try:
        interval = number(args.interval, "interval")
        if not 0 < interval <= 60:
            raise ValueError("interval must be greater than 0 and at most 60 seconds")
        if args.loop and not args.realtime:
            raise ValueError("--loop requires --realtime")
        config = load_config(args.config)
        rows = load_scenario(args.scenario)
        brightness = percentage(
            config.led.brightness_pct if args.led_brightness is None else args.led_brightness,
            "led brightness",
        )
    except (ValueError, OSError) as error:
        parser.error(str(error))

    logging.basicConfig(level=logging.INFO, format="%(levelname)s %(message)s")
    LOG.info("Simulation only: GPIO, fan power and GPS power are not controlled")
    controller = Controller(config)
    outputs = SimulatedOutputs()
    stop = threading.Event()
    old_handlers = {}
    if threading.current_thread() is threading.main_thread():
        for sig in (signal.SIGINT, signal.SIGTERM):
            old_handlers[sig] = signal.signal(sig, lambda *_: stop.set())
    render = render_json if args.format == "json" else render_text
    tick = 0
    mode = args.fan_mode
    enabled = args.led_on or config.led.enabled
    try:
        while not stop.is_set():
            for row in rows:
                if stop.is_set():
                    break
                mode = row.get("fan_mode", mode)
                enabled = row.get("led_enabled", enabled)
                brightness = row.get("led_brightness_pct", brightness)
                now = tick * interval
                status = controller.step(
                    reading_from_row(row, config.sensor.id, now), now,
                    fan_mode=mode, led_enabled=enabled, led_brightness_pct=brightness,
                )
                outputs.apply(status)
                print(render(status), flush=True)
                tick += 1
                if args.realtime:
                    stop.wait(interval)
            if not args.loop:
                break
    finally:
        outputs.close()
        for sig, handler in old_handlers.items():
            signal.signal(sig, handler)
        LOG.info("Simulation stopped; no physical outputs were changed")
    return 0

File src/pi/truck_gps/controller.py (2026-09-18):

"""Deterministic control decisions independent of displays and networks."""

from dataclasses import asdict, dataclass
from .config import Config, number, percentage
from .sensors import Reading


@dataclass(frozen=True)
class Status:
    elapsed_s: float
    sensor_id: str
    temperature_c: float | None
    sensor_age_s: float | None
    sensor_fault: str | None
    fan_mode: str
    fan_requested_pct: float
    fan_reason: str
    led_enabled: bool
    led_brightness_setting_pct: float
    led_requested_pct: float
    simulated: bool = True
    fan_rpm: int | None = None
    gps_power: bool | None = None

    def to_dict(self) -> dict:
        return asdict(self)


class Controller:
    def __init__(self, config: Config):
        self.config = config
        self._fan_active = False
        self._last_tick: float | None = None

    def step(
        self, reading: Reading | None, now_s: float, *, fan_mode: str = "auto",
        led_enabled: bool | None = None, led_brightness_pct: float | None = None,
    ) -> Status:
        now_s = number(now_s, "now_s")
        if self._last_tick is not None and now_s < self._last_tick:
            raise ValueError("controller time must not move backwards")
        if fan_mode not in ("auto", "boost"):
            raise ValueError("fan_mode must be auto or boost")
        enabled = self.config.led.enabled if led_enabled is None else led_enabled
        if not isinstance(enabled, bool):
            raise ValueError("led_enabled must be a boolean")
        brightness = percentage(
            self.config.led.brightness_pct if led_brightness_pct is None else led_brightness_pct,
            "led_brightness_pct",
        )
        self._last_tick = now_s
        temperature, age, fault = self._inspect(reading, now_s)
        cfg = self.config.fan
        if fault:
            duty, reason = 100.0, "sensor_fault"
            self._fan_active = True
        elif fan_mode == "boost":
            duty, reason = 100.0, "manual_boost"
            self._fan_active = True
        else:
            assert temperature is not None
            if temperature >= cfg.start_c:
                self._fan_active = True
            elif temperature <= cfg.stop_c:
                self._fan_active = False
            if not self._fan_active:
                duty, reason = 0.0, "below_start"
            else:
                fraction = max(0.0, min(1.0, (temperature - cfg.start_c) / (cfg.full_c - cfg.start_c)))
                duty = cfg.min_duty_pct + fraction * (100 - cfg.min_duty_pct)
                reason = "temperature_curve" if temperature >= cfg.start_c else "hysteresis"
        return Status(
            elapsed_s=now_s, sensor_id=self.config.sensor.id,
            temperature_c=temperature, sensor_age_s=age, sensor_fault=fault,
            fan_mode=fan_mode, fan_requested_pct=round(duty, 2), fan_reason=reason,
            led_enabled=enabled, led_brightness_setting_pct=brightness,
            led_requested_pct=brightness if enabled else 0.0,
        )

    def _inspect(self, reading: Reading | None, now_s: float):
        if reading is None:
            return None, None, "missing_sensor"
        if reading.sensor_id != self.config.sensor.id:
            return None, None, "wrong_sensor"
        try:
            sampled = number(reading.sampled_at_s, "sampled_at_s")
        except ValueError:
            return None, None, "invalid_timestamp"
        age = now_s - sampled
        if age < 0:
            return None, None, "future_timestamp"
        if reading.error:
            return None, age, reading.error
        if age > self.config.sensor.stale_after_s:
            return None, age, "stale_sensor"
        try:
            temperature = number(reading.temperature_c, "temperature_c")
        except ValueError:
            return None, age, "invalid_temperature"
        if not self.config.sensor.min_valid_c <= temperature <= self.config.sensor.max_valid_c:
            return None, age, "temperature_out_of_range"
        return temperature, age, None

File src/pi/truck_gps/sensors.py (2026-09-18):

"""Timestamped samples and a pure parser for future Linux 1-Wire integration.

No device reads, retries, threads or GPIO imports happen in this module.
"""

from dataclasses import dataclass
import re


@dataclass(frozen=True)
class Reading:
    sensor_id: str
    temperature_c: float | None
    sampled_at_s: float
    error: str | None = None


def parse_w1(text: str, sensor_id: str, sampled_at_s: float) -> Reading:
    """Parse one captured w1_slave sample; CRC failures never become 0°C."""
    def fault(reason: str) -> Reading:
        return Reading(sensor_id, None, sampled_at_s, reason)

    if not text:
        return fault("missing_sample")
    if len(text) > 4096:
        return fault("oversized_sample")
    lines = text.splitlines()
    if len(lines) != 2:
        return fault("malformed_sample")
    if not lines[0].split() or lines[0].split()[-1] != "YES":
        return fault("crc_error")
    match = re.search(r"(?:^|\s)t=(-?\d{1,7})\s*$", lines[1])
    if not match:
        return fault("malformed_temperature")
    return Reading(sensor_id, int(match.group(1)) / 1000.0, sampled_at_s)

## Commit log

2026-09-17 Restructure project for truck GPS telemetry system
    Move CAD assets under `src/stl`, add API references, and update
    documentation for Raspberry Pi telemetry, Tailscale networking, and
    home map display planning.
    [accessory_test.stl, bolt_cover_test.stl, dash_bolt_test.stl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]
2026-09-17 Document PWM fan cooling and temperature control setup
2026-09-17 docs: select Pi Zero 2 W and 20 mm PWM fan; document bring-up and v0.4 plan
